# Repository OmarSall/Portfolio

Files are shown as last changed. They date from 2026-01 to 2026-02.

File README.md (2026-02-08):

# 🇪🇸 Portfolio de Ingeniería

Este repositorio contiene una selección de proyectos de ingeniería centrados en diseño mecánico, desarrollo estructural y optimización del rendimiento. El trabajo presentado incluye modelado CAD, procesos de diseño iterativo, validación mediante simulaciones (CFD / análisis estructural) y consideraciones de prototipado, principalmente en aplicaciones aeroespaciales y energéticas.

Los proyectos completos de ensamblaje y la documentación asociada están disponibles en este repositorio.

# 🇬🇧 Engineering Portfolio

This repository contains a selection of engineering projects focused on mechanical design, structural development and performance-driven optimization. The work presented includes CAD modeling, iterative design processes, simulation-based validation (CFD / structural analysis) and prototyping considerations, primarily within aerospace and energy-related applications.

The complete assembly projects and supporting documentation are available within this repository.

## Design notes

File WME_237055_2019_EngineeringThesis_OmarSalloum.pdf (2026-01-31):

Wydział Mechaniczno-Energetyczny kierunek studiów: Mechanika i Budowa Maszyn specjalność: Inżynieria lotnicza

# PRACA DYPLOMOWA INŻYNIERSKA

## Projekt wstępny wentylatora silnika dwuprzepływowego o ciągu

210 kN.

### Omar Salloum

Opiekun pracy
Dr inż. Roman Róziecki

Wrocław 2019

STRONA 3 Z 75

STRESZCZENIE

Celem pracy jest wykonanie projektu wstępnego jednostopniowego, naddźwiękowego wentylatora osiowego dla dwuprzepływowego turbinowego silnika odrzutowego o wysokim stopniu dwuprzepływowości charakteryzującego się siłą ciągu 210 kN. Poprzez analizę
układów | konstrukcyjnych | dwuprzepływowych | silników | odrzutowych | obecnie
eksploatowanych w statkach powietrznych linii lotniczych, uzyskano dane pozwalające wykonać wstępne obliczenia gazodynamiczne wentylatorowego silnika dwuprzepływowego. Następnie dokonano szczegółowych obliczeń gazodynamicznych jednostopniowego naddźwiękowego wentylatora. Na podstawie uzyskanych wyników sporządzono obliczenia wytrzymałościowe łopatek wirnikowych, zamków i tarczy wentylatora. Znając wymiary geometryczne wentylatora zaprojektowano w programie SolidWorks aparat kierujący, wirnik oraz pośrednie części konstrukcyjne tworzące razem jedną całość – wentylator. Bazując na wykonanym modelu sporządzono rysunki wykonawcze łopatki wirnikowej i tarczy wentylatora.

Słowa kluczowe: wentylator, silnik dwuprzepływowy.

ABSTRACT

The aim of this paper is to realize the preliminary draft of the one stage, supersonic, axial fan for the high by-pass ratio turbo-jet engine with the thrust of 210 kN. By the analysis of the high by-pass ratio turbo-jet engine that are currently applied for airline airplanes, obtained general and circumstantial gas-dynamic calculations. Taking into consideration gas-dynamic calculations, rotor blade, locks and fan’s disc strength calculations were made. Having known the geometry of the fan, digital 3D model of rotor, stator and intake casing were designed thanks to the computer aided design program SolidWorks. The last part of the paper is working drawing of the rotor blade and fan’s disc.

Keywords: fan, high by-pass ratio.

STRONA 4 z 75

STRONA 5 z 75

SPIS TREŚCI

5. Obliczenia wytrzymałościowe łopat wirnikowych, zamków i tarczy wentylatora na

5.1.Obliczenia wytrzymałościowe łopat wirnika wentylatora na rozciąganie siłą masową. 55

5.2.Obliczenia wytrzymałościowe zamków wentylatora na rozciąganie siłą masową. ...... 60

STRONA 6 z 75

WYKAZ SKRÓTÓW I OZNACZEŃ

A − pole powierzchni przekroju
a – lokalna prędkość dźwięku
C – godzinowe zużycie paliwa

Cs − sekundowe zużycie paliwa

c − prędkość bezwzględna

cP − ciepło właściwe przemiany izobarycznej

lw − praca efektywna wentylatora

m̅ − stosunek natężeń przepływów (współczynnik dwuprzepływowości silnika)

pH − ciśnienie statyczne otoczenia
R – indywidualna stała gazowa (dla powietrza R=287 J
kg∗K

)
u − prędkość obwodowa
w − prędkość względna

ηst

∗ − sprawność stopnia (wentylatora)

ηII − sprawność kanału zewnętrznego

κ − wykładnik izentropy (dla powietrza κ = 1,4)

μ − stopień obciążenia turbiny
π

∗ − spręż silnika

πS

∗ − spręż sprężarki

πW

∗ − spręż wentylatora

πWL

∗ − spręż wlotu

σWL – współczynnik strat ciśnienia całkowitego we wlocie

τ − względne zużycie paliwa

AK – aparat kierujący/wieniec kierujący/wieniec dyfuzorowy WW − wieniec wirnikowy
1 − 1 przekrój przed wieńcem wirnikowym wentylatora 1′ − 1′ przekrój za wieńcem wirnikowym wentylatora 1′′ − 1′′ przekrój za aparatem kierującym wentylatora

STRONA 7 z 75

WSTĘP

Wraz z rozwojem techniki i wymaganiami ekologicznymi dotyczącymi mniejszej emisji spalin silników lotniczych, zaczęły przeważać silniki dwuprzepływowe. Zadaniem wentylatora jest doprowadzenie powietrza o określonym strumieniu masy i ciśnieniu do wlotu sprężarki oraz tłoczenie wymaganej ilości powietrza do kanału zewnętrznego silnika pod ciśnieniem umożliwiającym wypływ z tego kanału z odpowiednią prędkością, przy zachowaniu właściwej wartości ciśnienia, umożliwiających wytworzenie ciągu. Obecnie dąży się do uzyskania coraz większej wartości strumienia masy powietrza w kanale zewnętrznym (większy stopień dwuprzepływowości), co implikuje mniejszą emisję spalin, mniejszy hałas, ale również większe wymiary promieniowe wentylatora (silnika). Skutkiem tego może być osiąganie prędkości naddźwiękowych końcówek łopat wentylatora co jest sporym problemem związanym z niestateczną pracą sprężarki wywołaną gwałtownymi zmianami ciśnienia, które zostały wygenerowane przez falę uderzeniową. Elementy wentylatorów są zagrożone podczas lotu na zderzenia z kroplami wody, bryłkami gradu, pojedynczymi ptakami lub ich stadami, a podczas startu czy lądowania na zderzenia z ziarnami piasku, wyrwanymi z podłoża i zassanymi przez wir wlotowy okruchami nawierzchni i innymi ciałami obcymi. Skutki zderzeń są bardzo groźne, ponieważ prędkości obwodowe wierzchołków łopat wentylatorów przekraczają 500 m/s, co stanowi o energii zderzeń zbliżonych do energii pocisków opuszczających lufy broni strzeleckiej. [1]

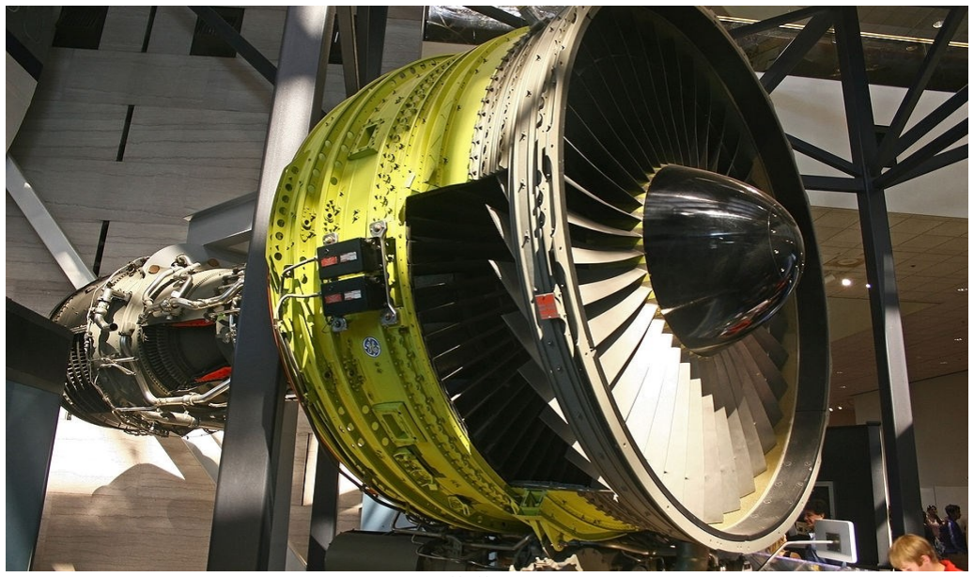
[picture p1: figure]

STRONA 8 z 75

1. ANALIZA | UKŁADÓW | KONSTRUKCYJNYCH | DWUPRZEPŁYWOWYCH
SILNIKÓW ODRZUTOWYCH.

Analiza układów konstrukcyjnych zawiera przegląd czterech najbardziej popularnych wentylatorowych silników turbinowo – odrzutowych o wysokim stopniu dwuprzepływowości stosowanych w lotnictwie cywilnym, w liniach lotniczych. Są to takie silniki jak: GE CF6, RB211, GE90 oraz GEnx. Znając rząd wartości charakterystycznych wielkości tj.: jednostkowe zużycie paliwa, sumaryczny strumień masy, stosunek natężeń przepływów, spręż oraz wymiary promieniowe wentylatora, dobrano wartości tych wielkości.

Pierwszym rozpatrywanym silnikiem jest turbowentylatorowy dwuprzepływowy, dwuwałowy silnik lotniczy CF6 firmy General Electric (USA) o ciągu 27 000 daN (rys.1.1). Charakteryzuje się jednostkowym zużyciem paliwa cj = 0,36 kg
| | daN∙ℎ

, sumarycznym strumieniem masy ṁ Σ = 874 kg
s

, stosunkiem natężeń przepływów m̅ = 5,3 oraz sprężem π

| | | ∗ = 34,8. Wymiary

promieniowe silnika GE CF6 o masie 5 091,6 kg są zdefiniowane przez jego średnicę o wartości d = 2 873,5 mm.
W większości przypadków średnica silnika jest ekwiwalentem średnicy zewnętrznej wentylatora.[2]

Rys. 1.1 Silnik GE CF6 [5].

GE CF6 napędza takie statki powietrzne jak: Airbus A330-200, A330 oraz Boeing 767,747. Jednostopniowy wentylator (WW+ AK) składa się z wieńca wirnikowego posiadającego 38 łopatek.

Łopatki wirnikowe wentylatora silnika GE CF6 posiadają półki, których obecność stanowi element antywibracyjny. Pod względem wytrzymałości piór łopatek wirnikowych półki stanowią poważne obciążenie – ze skokową zmianą naprężeń w miejscu usytuowania półki.[1]

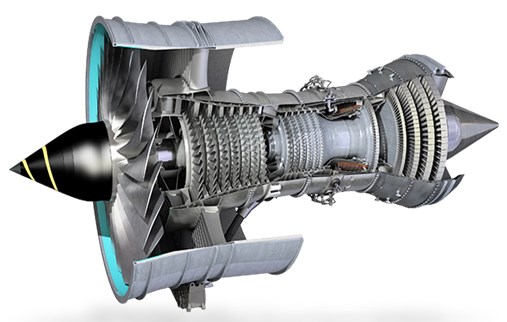
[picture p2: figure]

STRONA 9 z 75

Następnym | rozpatrywanym | silnikiem | jest | turbowentylatorowy, | dwuprzepływowy,
trójwałowegy silnik RB211 firmy Rolls – Royce (Wielka Brytania) przedstawiony w formie przekroju na rys.1.2. Silnik generuje siłę ciągu 33 430 daN oraz waży 6 271 kg. Charakteryzuje się sprężem o wartości π

∗ = 35,3; sumarycznym strumieniem masy ṁ Σ = 1 225 kg
| | | | | s ,
stosunkiem natężeń przepływów m̅ = 8,7 oraz jednostkowym zużyciem paliwa o wartości cj = 0,41 kg
daN∙ℎ

. Średnica silnika równoważna średnicy zewnętrznej wentylatora wynosi d = 3 944 mm.

Rys. 1.2 Przekrój silnika RB211. [7]

RB 211 napędza takie statki powietrzne jak: Boeing 747,757,767, Airbus A-380 oraz Tupolew Tu 204. [2]

W silniku RB 211 naddźwiękowy wentylator jest jednostopniowy (WW + AK), składa się z 22 tytanowych łopat o charakterystycznej szerokiej cięciwie aerodynamicznej oraz jest napędzany przez trójstopniową turbinę niskiego ciśnienia. [8]

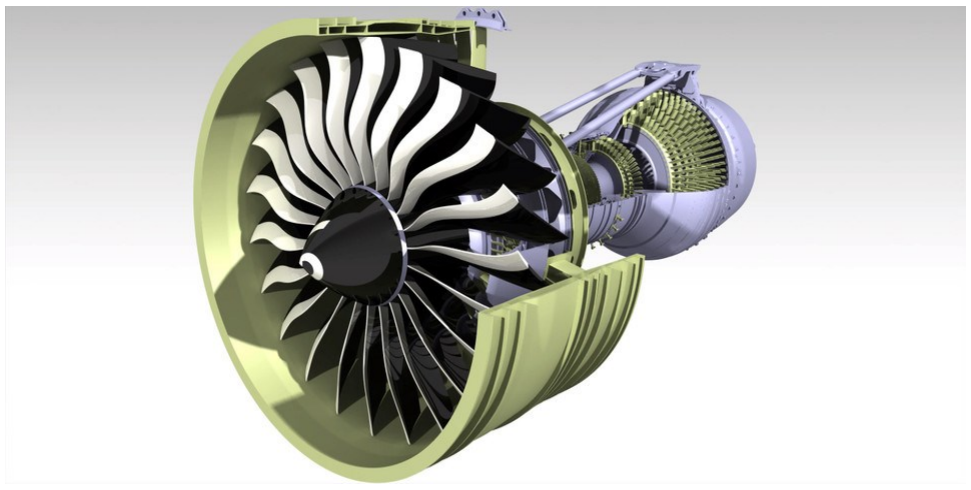
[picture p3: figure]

STRONA 10 z 75

Kolejnym | rozpatrywanym | silnikiem | w | analizie | układów | konstrukcyjnych | jest
turbowentylatorowy, dwuprzepływowy o dużym stopniu dwuprzepływowości silnik GE90 firmy General Electric (USA), przedstawiony w postaci przekroju na rys.1.3. GE90 charakteryzuje się sprężem π

∗ = 40, stosunkiem natężeń przepływów m̅ = 9, sumarycznym strumieniem masy ṁ Σ = 1 361 kg
| | | | s

, jednostkowym zużyciem paliwa cj = 0,29 kg
| daN∙ℎ
, | średnicą opisującą wymiary promieniowe d = 3 944 mm, siłą ciągu o
wartości 33 550 daN i masą 7 559 kg.

Rys. 1.3 Silnik GE90. [9]

GE90 napędza takie statki powietrzne jak Boeing 777-200/200ER. Naddźwiękowy wentylator składa się z wieńca wirnikowego, który posiada 22 łopaty o szerokiej cięciwie aerodynamicznej, wykonane z włókna węglowego, ze wzmacniającą matrycą epoksydową, oraz aparatu kierującego. Łopaty WW są unikalnie zaprofilowane, usprawniając aerodynamikę, co ma znaczący wpływ na jednostkowe zużycie paliwa. Krawędź natarcia
każdej | łopaty jest | wzmocniona | tytanową | nakładką. | Wentylator | jest | zasilany
6-stopniową turbiną niskiego ciśnienia. [10]

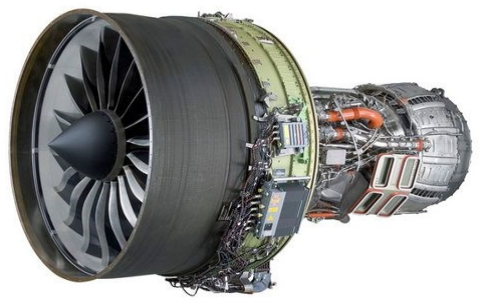
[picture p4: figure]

STRONA 11 z 75

Ostatnim analizowanym silnikiem jest turbowentylatorowy, dwuprzepływowy, dwuwałowy silnik GEnx (rys.1.4) firmy General Electric (USA) o sile ciągu 29 580 daN, charakteryzuje się sprężem π

∗ = 44,7; stosunkiem natężeń przepływów m̅ = 8, wagą 5 623 kg oraz średnicą d = 2 659,4 mm.

Rys. 1.4 Silnik GEnx [11]

GEnx napędza takie statki powietrzne jak Boeing 787, 747-8. Naddźwiękowy, jednostopniowy (WW+AK) wentylator zasilany jest 7-stopniową turbiną niskiego ciśnienia. Łopaty wieńca wirnikowego, charakteryzujące się szeroką cięciwą aerodynamiczną, wykonane są z materiału kompozytowego, m.in. włókna węglowego. Krawędź natarcia łopaty jest wzmocniona tytanową nakładką. W silniku GEnx zredukowano ilość łopat z 22 do 18. Opisana struktura wentylatora usprawnia aerodynamikę, zmniejsza zużycie paliwa, redukuje poziom hałasu oraz zwiększa siłę ciągu. [11],[12]

STRONA 12 z 75

Bazując na przedstawionej analizie konstrukcyjnej sporządzono tabelę zbiorczą (Tab.1.1), w celu oszacowania wartości niezbędnych do obliczeń gazodynamicznych silnika.

Tab. 1.1. Dane techniczne silników opisanych w rozdziale 1.

Dla | rozpatrywanych | parametrów | silników | GECF6, | RB211, | GE90 | oraz | GEnx
policzono wartości średnie.

Skorzystano ze wzoru na średnią arytmetyczną:

xśr =

xi

i=n
i=1
n

(1.1)

Wielkości charakteryzujące dany silnik zamieszczone w tabeli 1.1 mają indeksy: dla GE CF6 – 1, dla RB211 – 2, dla GE90 – 3 oraz dla GEnx – 4.

Zatem średnie jednostkowe zużycie paliwa wynosi:

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
+ cj
2

+ cj
3
3

(1.2)

Dla cj1

= 0,36 kg
daN∗ℎ

, cj2

= 0,41 kg
daN∗ℎ

, cj3

= 0,29 kg
daN∗ℎ

cj
śr

= 0,35

kg
daN ∙ ℎ
Średni sumaryczny strumień masy wynosi:

ṁ śr

=

ṁ
i

i=3
i=1
3

=

ṁ 1 + ṁ 2 + ṁ 3
3

(1.3)

Dla ṁ1 = 874 kg
s

, ṁ 2 = 1 225 kg
s

, ṁ 3 = 1 361 kg
s

ṁ śr = 1 153

kg
s
Silnik | Ciąg | Jednostkowe zużycie paliwa | Sumaryczny strumień masy | Stosunek natężeń przepływów | Spręż | Wymiary | Masa
| K | cj | ṁ Σ | m̅ | ∗ π | średnica
| daN | kg/daN·h | kg/s | - | - | mm | kg
GE CF6 | 27 000 | 0,36 | 874,0 | 5,3 | 34,8 | 2 873,5 | 5 091,6
RB211 | 33 430 | 0,41 | 1 225,0 | 8,7 | 35,3 | 3 944,0 | 6 271,0
GE90 | 33 550 | 0,29 | 1 361,0 | 9,0 | 40,0 | 3 944,0 | 7 559,0
GENX | 29 580 | - | - | 8,0 | 44,7 | 2 659,4 | 5 623,0

STRONA 13 z 75

Średni stosunek natężeń przepływów wynosi:

m̅śr =

m̅i

i=4
i=1
4

=

m̅1 + m̅2 + m̅3 + m̅4
4

(1.4)

Dla m̅1 = 5,3; m̅2 = 8,7; , m̅3 = 9; m̅4 = 8

m̅śr = 7,75

Średni spręż silnika wynosi:

πśr

∗
=

πc i

i=4
i=1
4

=

πc1 + πc 2 + πc3 + πc4
4

(1.5)

Dla π

∗
1 = 34,8; π

∗
2 = 35,3; π

∗
3 = 40; π

∗
4 = 44,7

π

∗
śr = 38,7

Średnia średnica silnika wynosi:

dśr =

dśr

i=4
i=1
4

=

d1 + d2 + d3 + d4
4

(1.6)

Dla d1 = 2 873,5 mm, d2 = 3 944 mm, d3 = 3 944 mm, d4 = 2 659,4 mm

dśr = 3 355,2 mm
Średnia masa silnika wynosi:

mśr =

mi

i=4
i=1
4

=

m1 + m2 + m3 + m4
4

(1.7)

Dla m1 = 5 091 kg, m2 = 6 271 kg, m3 = 7 559 kg, m4 = 5 623 kg

mśr = 6 136 kg

Na podstawie powyższych układów konstrukcyjnych dwuprzepływowych silników odrzutowych, w celu przeprowadzenia obliczeń gazodynamicznych silnika dobrano:

- Wartość stosunku natężeń przepływów m̅ = 7,75
- Założono spręż silnika πzał

∗ = 30

Średnie wartości jednostkowego zużycia paliwa, średnicy silnika, sumarycznego strumienia masy oraz masy silnika będą potrzebne w dalszej części pracy, w celu porównania z wartościami wyliczonymi. Dzięki takiemu porównaniu można dowiedzieć się czy uzyskane wartości są zbliżone do wartości powyższych wielkości charakteryzujących obecnie eksploatowane silniki w przemyśle lotniczym.

STRONA 14 z 75

### 2. WSTĘPNE OBLICZENIA GAZODYNAMICZNE SILNIKA

W celu przeprowadzenia wstępnych obliczeń gazodynamicznych wentylatorowego silnika dwuprzepływowego założono pracę silnika w warunkach statycznych na ziemi (cH = 0, MaH = 0, TH

∗ = 288,15 K, pH = 101325 Pa) oraz temperaturę całkowitą przed turbiną T3

∗ = 1550 K.

Na podstawie analizy przeprowadzonej w rozdziale 1 dobrano wartość stosunku natężeń przepływów m̅ = 7,75.

Założono spręż silnika πzał

∗ = 30.

Miernikiem efektywności działania wlotu jest jego spręż:

πWL

∗
=

p1

∗
pH

(2.1)

p1

∗
- ciśnienie całkowite przed wieńcem wirnikowym wentylatora

Straty ciśnienia we wlocie określa współczynnik strat ciśnienia całkowitego:

σWL =

p1

∗
pH

∗

(2.2)

Parametry spiętrzenia można wyrazić jako funkcje gazodynamiczne liczby Macha i statycznej wartości danego parametru:

2 2 2 c c c κ − 1 T ∗ = T + = T 1 + = T 1 + = T 1 + Ma 2 κ 2 2cp 2 2 RT a 2 κ − 1 κ − 1

| (2.3)

T

∗ = T 1 +

κ − 1
2

Ma

2

Proces spiętrzenia strumienia (wyhamowywania) potraktowano jako izentropowy:

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
∗ = p 1 +

κ − 1
2

Ma

2

κ
κ−1
(2.4)

Przekształcając wzór (2.1):

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
(2.5)

oraz wykorzystując zależność (2.4) otrzymano:

πWL

∗
= σWL 1 +

κ − 1
2

Ma

2

κ
κ−1
(2.6)

STRONA 15 z 75

Zatem zakładając warunki statyczne na ziemi (podstawiając do wzoru 2.6 Ma = 0 oraz σWL = 0,99 (krótki wlot powietrza)) spręż wlotu wynosi:

πWL

∗
= σWL = 0,99 ≈ 1

### 2.1. PRACA OBIEGU

Rozporządzalną (użyteczną) pracę obiegu w kanale wewnętrznym określa następujący wzór:

lob =

κ
κ − 1

RTH

eI − 1

ηprs
I

kIΔI

∗ηprs
I

ηprr
I
eI
− 1 | (2.7)

W celu wyznaczenia wartości pracy obiegu należy wyznaczyć:

a) Stopień podgrzania powietrza sprężanego izentropowo w silniku

epoc zI

= πzał

∗

κ−1
κ | (2.8)

epoczI = 30

1,4−1
1,4 = 2,642
b) Sprawność procesu sprężania w silniku

ηprs
I

= 0,83… 0,85; założono ηprs
I

= 0,84

c) Stopień podgrzania powietrza w silniku

ΔI

∗ =

1550
288,15

= 5,379

d) Sprawność procesu rozprężania spalin w silniku

ηprr
I

= 0,88 … 0,92; założono ηprr
I

= 0,9

e) Współczynnik k uwzględniający różnicę między ciepłami właściwymi spalin i powietrza

Wartość współczynnika kI odczytano z wykresu (rys.2.1.) Temperatura całkowita przed turbiną wynosi T3

∗ = 1550 K, zatem dla sprężu silnika πzał

∗ = 30, dobierając krzywą
pomiędzy krzywymi dla wartości T3

∗ = 1400 K i T3

∗ = 1600 K można aproksymować wykres funkcji, która przyjmuję wartość 1,045.

ΔI

∗
=

T3

∗

TH

(2.9)

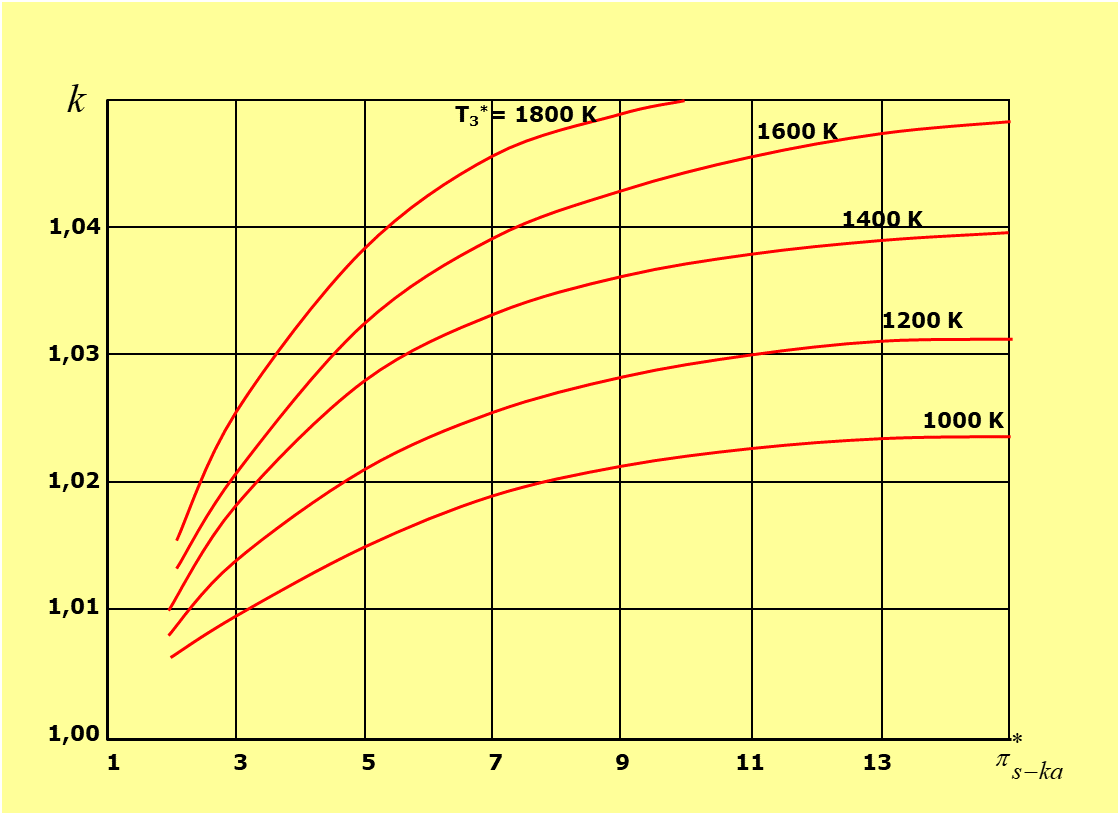
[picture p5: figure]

STRONA 16 z 75

Rys. 2.1. Zależność współczynnika k od sprężu silnika i temperatury przed turbiną. Zatem:
kI = 1,045
Podstawiając powyższe wartości do wzoru (2.7) otrzymano wartość lob = 344,283 kJ
kg

W celu optymalizacji pracy obiegu należy ją rozpatrzeć jako funkcję od zmiennej e [lob = f(e)]. Różniczkując badaną funkcję po zmiennej e oraz przyrównując wyliczoną pochodną funkcji do zera, można otrzymać optymalną wartość stopnia podgrzania powietrza sprężanego izentropowo w silniku (eopt), dającą maksymalną wartość pracy obiegu (ekstremum funkcji lob = f(e)).

lob max

= f(eopt
I
) | (2.10)

∂lob
∂eI

=

∂
∂eI

κ
κ − 1

RTH

eI − 1

ηpr sI

kIΔI

∗ηpr sI
ηpr rI
eI
− 1 | (2.11)

∂lob
∂eI

=

κ
κ − 1

RTH

kIΔI

∗ηpr rI
eI

2 −

1

ηpr sI

(2.12)

∂lob
∂eI

= 0 ⇒

kIΔI

∗ηpr rI
eI

2 =

1

ηpr sI

→ eoptI

= kIΔI

∗ηpr sI
ηpr rI
(2.13)

Podstawiając eoptI = 2,061 do wzoru na rozporządzalną pracę obiegu otrzymano:

lob max

| = f eop tI

= 388,239

kJ
kg

STRONA 17 z 75

Na podstawie optymalnej wartości stopnia podgrzania powietrza sprężanego izentropowo w silniku, która daje maksymalną wartość pracy obiegu, można wyliczyć optymalną wartość sprężu silnika:

eop tI

= κΔI

∗ηpr sI
ηpr rI

= πoptI

∗

κ−1
κ ⟹ πoptI

∗
= (kIΔI

∗ηpr sI
ηpr rI

)

κ
2(κ−1)
(2.14)

Zatem, dla: kI = 1,045; ηprrI = 0,9; ΔI

∗ = 5,379; ηprsI = 0,84; otrzymano:

πoptI

∗
= (1,045 ∙ 5,379 ∙ 0,84 ∙ 0,9)

1,4
2(1,4−1) = 12,577

Optymalna wartość stopnia podziału pracy obiegu między kanały silnika, odpowiadająca maksymalnemu ciągowi jednostkowemu i minimalnemu zużyciu paliwa można wyrazić zależnością:

βopt =

ηII −

cH

2

2lob

(1 − ηII

)
1
m̅

− ηII

(2.15)

Dla cH = 0:

βopt =

ηII
1
m̅

− ηII

(2.16)

Zakładając wartość sprawności kanału zewnętrznego ηII = 0,77 i m̅ = 7,75:

βopt =

0,77
1
7,75 − 0,77

= 0,85

Dla każdej wartości stopnia podziału pracy obiegu między kanały silnika przyporządkowana jest określona wartość sprężu wentylatora (wzrost β odpowiada wzrostowi sprężu wentylatora).

πW

∗
opt

=

βopt

lob ηW

∗

m̅

κ
κ − 1

RTH

+ 1

κ
κ−1
(2.17)

Zakładając wartość sprawności wentylatora ηW

∗ = 0,88; lob = lobmax = 388,239 kJ kg

;
TH = 288,15 K:

πWopt

∗ =

0,85 ∙ 388,239 ∙ 0,88

7,75 ∙

1,4
1,4 − 1

287 ∙ 288,15

+ 1

1,4
1,4−1
= 1,5

STRONA 18 z 75

Ciąg jednostkowy można wyliczyć ze wzoru:

kj =

1
1 + m̅

kj
I

+ m̅kJ
II

(2.18)

Ciąg jednostkowy kanału wewnętrznego:

Dla cH = 0 oraz lob = lobmax

kjI

= 2(1 − β)lob
(2.20)

kj
I

= 2(1 − 0,85) ∙ 388 239 = 333,83

m
s

Ciąg jednostkowy kanału zewnętrznego:

kj
II

= 2

β
m̅

lob +

cH

2
2

ηII − cH

(2.21)

Dla warunków statycznych oraz lob = lobmax :

kj
II

= 2

β
m̅

lob ηII

(2.22)

kj
II

= 2 ∙

0,85
7,75 ∙ 388 239 ∙ 0,77 = 257,05

m
s

Zatem wartość ciągu jednostkowego wynosi:

kj =

1
1 + 7,75

(333,83 + 7,75 ∙ 0,77) = 265,82

m
s

Strumień masy powietrza w zależności od wymaganego ciągu można wyznaczyć z poniższej zależności:

ṁ Σ =

K
kj

(2.23)

ṁ Σ =

210 000
265,82

= 790

kg
s

Korzystając z zależności określających stopień dwuprzepływowości i sumaryczny wydatek masowy powietrza można wyprowadzić wzór na strumień masy w kanale wewnętrznym i zewnętrznym.

kjI

= 2(1 − β)lob + cH

2 − cH
(2.19)

STRONA 19 z 75

m̅ =

ṁII
ṁ
I
ṁ Σ = ṁI + ṁII

⟹

ṁI =

ṁ Σ
m̅ + 1

ṁII =

ṁ Σm̅
m̅ + 1

(2.24)

ṁ

I =

790
7,75 + 1

= 89,26

kg
s

oraz ṁ

II =

790 ∙ 7,75
7,75 + 1

= 699,71

kg
s

Związek między podgrzaniem powietrza w sprężarce, a sprężem sprężarki przy założeniu
πWL

∗ ≈ 1:

πS

∗ =

eI

∗

κ
κ−1

πWL

∗ πW

∗ =

eI

∗

κ
κ−1
πW

∗

(2.25)

Postać analityczna funkcji opisującej zależność względnego zużycia paliwa od temperatury całkowitej za sprężarką dla poszczególnych wartości temperatury całkowitej przed turbiną:

τ = (3,1034 ∙ T3

∗ − 2,6897 ∙ T2
∗ − 380) ∙ 10⁻⁵
(2.26)

Temperaturę całkowitą za sprężarką, potrzebną do odczytu wartości τ można policzyć z następującego wzoru:

T2

∗ = TH

∗ 1 +

πS

∗

κ−1
κ − 1
ηS
∗ | (2.27)

Założono wartość sprawności efektywnej sprężarki w parametrach spiętrzenia: ηS

∗ = 0,85.

Jednostkowe zużycie paliwa definiuje wzór:

cj =

C
K

=

3600CS
K

=

3600 τ ṁ
I
K

(2.28)

Podstawiając zależności opisane wzorami (2.18), (2.20) oraz (2.22) do wzoru (2.23) otrzymano następującą zależność:

cj =

3600 ṁI

3,1034T3

∗ − 2,6897TH

∗
1 +

eI

∗

κ
κ−1
πWL

∗ πW

∗

κ−1
κ

ηS

∗

− 1

K

(2.29)

STRONA 20 z 75

Podstawiając wartości:

T3

∗ = 1550 K, TH

∗ = 288,15 K, πWL

∗ | = πopt
∗ | = 1,5; ηS = 0,85; ṁI = 89,26

kg
s

otrzymano:

cj =

3600 ∙ 89,26
3,1034 ∙ 1550 − 2,6897 ∙ 288,15

1 +

2,061

1,4
1,4−1
1,5

1,4−1
1,4

0,85

− 1

210 000

= 0,21

kg
daN ∙ ℎ

W celu wyznaczenia charakterystyki jednostkowego zużycia paliwa w funkcji stopnia podgrzania powietrza sprężanego izentropowo w silniku, należy wyprowadzić zależność wydatku masowego w kanale wewnętrznym od rozporządzalnej pracy obiegu.

Do wyznaczenia opisanej powyżej zależności należy skorzystać z poniższego wzoru:

K = ṁ Σkj = (ṁ

I + ṁ
II

)

1
1 + m̅

kj
I

+ m kj
II

(2.30)

Podstawiając zależność (2.20) i (2.22) otrzymano:

K = ṁ
I

(1 + m̅)

1
1 + m̅

2(1 − β)lob + m 2

β
m̅
lob ηII | (2.31)

ṁI =

K

lob 2(1 − β) + m̅(m̅ + 1) 2

β
m̅

ηII

(2.32)

Maksymalnej wartości pracy obiegu lobmax = 388,239 kJ
kg

, odpowiada wartość jednostkowego zużycia paliwa cj = 0,21 kg
daN∙ℎ

. Zakładając warunki ekonomiczne, wartość pracy obiegu

wynosi lobek = 138 kJ
kg

dla cjmin = 0,15 kg
daN∙ℎ

(rys.2.2). Wybór warunków ekonomicznych nie

jest najlepszym rozwiązaniem, głównie ze względu na zbyt duży spadek wartości lob (spadek o 64,46%) przy 25% spadku cj

Na podstawie powyższych zależności dobrano lob(e = 2,4) = 372 kJ
kg

oraz cj = 0,176 kg
daN∙ℎ
Zmniejsza to zużycie paliwa w ciągu sekundy o 0,14 kg
s

, co w przypadku dwugodzinnego lotu (dla samolotu pasażerskiego) oszczędza 1008 kg paliwa (1230 litrów).

STRONA 21 z 75

Cena nafty lotniczej wynosi średnio 4,62 zł/litr, zatem dla dwugodzinnego lotu potencjalne linie lotnicze mogłyby zyskać około 6 tys. złotych. Zakładając średni nalot 80 godzin w miesiącu (960 godzin w ciągu roku), roczny zysk osiąga wartość 2,88 mln PLN.

Finalne parametry gazodynamiczne silnika:

K = 210 kN, cj = 0,176

kg
daN ∙ ℎ

, lob = 372

kJ
kg , m̅ = 7,75 ; Δ

∗ = 5,379; ηprr = 0,9; πWL

∗ = 1

ηprs = 0,84; π

∗ = 21,4; ηII = 0,77; βopt = 0,85; πW

∗ = 1,48; kj
I

= 326,77

m
s

;

kj
II

= 251,61

m
s

; kj = 260,2

m
s

; ṁ Σ = 807,07

kg
s

; ṁ

I = 92,23

kg
s

; ṁ

II = 714,84 | kg s

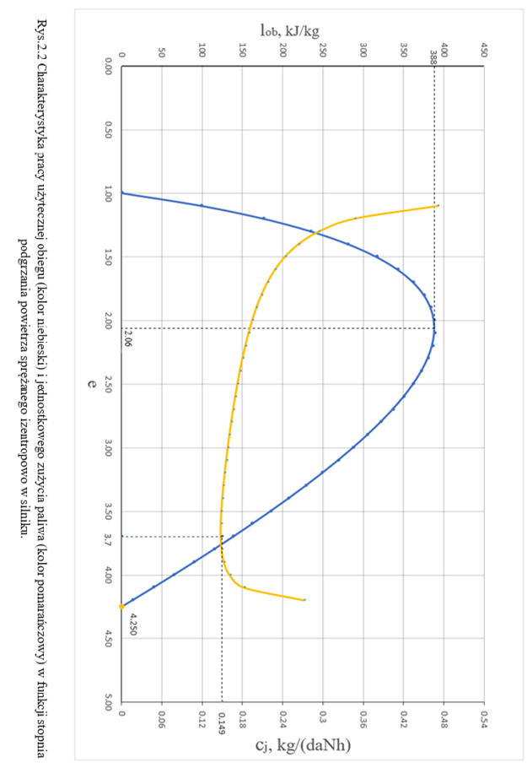
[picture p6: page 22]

STRONA 22 z 75

STRONA 23 z 75

### 3. WYMIARY GEOMETRYCZNE WENTYLATORA

W celu wyznaczenia wymiarów promieniowych wentylatora należy dobrać następujące wyjściowe parametry do obliczeń:

1. Prędkość bezwzględna strumienia powietrza c1 w przekroju wejściowym wieńca wirnikowego wentylatora (1-1): c1 = 170 m
s

,

2. Względna średnica wewnętrzna: D1

̅̅̅ =

Dw
Dz

= 0,28
3. Prędkość obwodowa wentylatora na średnicy zewnętrznej uz1 = 380 m
s

,
4. Liczba Macha w przekroju wejściowym na promieniu zewnętrznym odnosząca się do prędkości względnej: Mawl =

w1
a1

= 1,3

Na rysunku 3.1 przedstawiono charakterystyczne wielkości geometryczne opisujące wieniec wirnikowy (średnica zewnętrzna, średnica wewnętrzna i długość pióra łopaty), a na rysunku 3.2 zaznaczono trzy najważniejsze przekroje uwzględniane w obliczeniach (przekrój przed wieńcem wirnikowym 1 − 1, przekrój za wieńcem wirnikowym 1

′ − 1

′
, oraz za aparatem
kierującym 1′′ − 1′′).

Rys. 3.1. Podstawowe wielkości geometryczne opisujące wieniec wirnikowy.

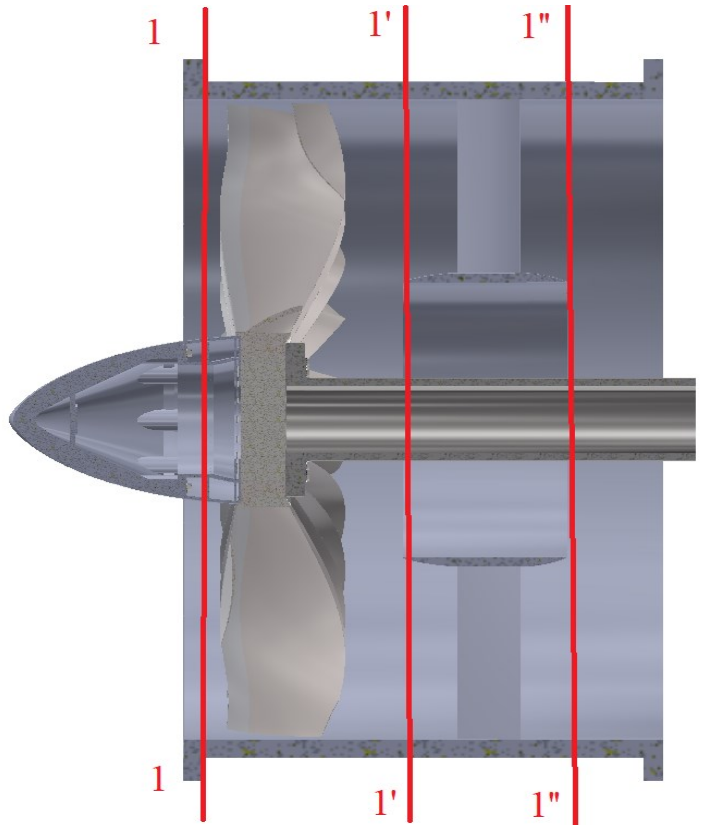
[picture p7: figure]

STRONA 24 z 75

Rys. 3.2 Charakterystyczne przekroje wentylatora (1 − 1, 1

′ − 1

′
, 1′′ − 1′′)

Parametry strumienia na średnim promieniu w przekroju przed wieńcem wirnikowym stopnia wentylatora:

- temperatura statyczna T1
(c1 = 170 m
s

; T1

∗ = TH

∗ = 288,15 K; R = 287 J
kg∙K

)

T1 = T1

∗ −

c1a

2

2

κ
κ − 1

R

(3.1)

T1 = 288,15 −

170²

2∙

1,4
1,4−1

∙287

= 273,77 K

- prędkość dźwięku a1:

a1 = κRT1
(3.2)

a1 = √1,4 ∙ 287 ∙ 273,77 = 331,66 m
s

STRONA 25 z 75

- prędkość względna w1:

w1 = Maw1

a1 | (3.3)

w1 = 1,3 ∙ 331,66 = 431,16 m
s
Prędkość obwodowa na średnim promieniu z uwzględnieniem profilowania łopatek wg prawa stałej reakcyjności (uz1 = 380 m
s

):

uśr1 = uz1

Dśr
Dz

= uz1

1 + D1

̅̅̅

2

2

(3.4)

Dla D1

̅̅̅ = 0,28 → u1śr = 380 ∙

1+0,28²

2

= 279 m
s

Pole powierzchni wieńca wirnikowego stopnia wentylatora:

Aw

=

ṁ Σ T1

∗
km ∙ j ∙ q1
- sinα1
- p1

∗

(3.5)

km − współczynnik korekcyjny uwzględniający prawo zmienności parametrów strumienia wzdłuż pióra łopatek oraz wpływ warstwy przyściennej kanału (km = 0,99)

j =

2
κ + 1

κ+1
2(κ−1)
∙

κ
R

(3.6)

Dla powietrza (κ = 1,4 oraz R = 287 J
kg∙K

):j ≈ 0,04041

Gęstość względna masy strumienia:

q1 =

cρ

ckr ρkr

=

Ma1√κRT

p
RT
2
κ − 1

κ+1
2(κ−1)

κ
R

p

∗
√T
∗

= Ma1

2
κ + 1

1 +

κ − 1
2

Ma1

2

−

κ+1
2(κ−1)
(3.7)

Dla przekroju 1-1 (dla Ma1 =

c1
a1

= 0,513):

q1 = 0,531 ∙

2
1,4 + 1

1 +

1,4 − 1
2

0,531²

−

1,4+1
2(1,4−1)
= 0,7596

Kąt zawarty między kierunkiem prędkości bezwzględnej w przekroju wejściowym, a płaszczyzną tego przekroju: α1 = 90°.

STRONA 26 z 75

Ciśnienie całkowite w przekroju 1-1 równe jest ciśnieniu całkowitemu w przekroju przed silnikiem (H-H) pomniejszonemu o straty ciśnienia całkowitego:

p1

∗
= σWL
- pH

∗
= σWLpH 1 +

κ − 1
2

MaH

2

κ
κ−1
(3.8)

W warunkach statycznych (MaH = 0) oraz dla σWL = 0,99:

p1

∗ = 101325 ∙ 0,99 = 100 312 Pa

Korzystając z równania ciągłości:

ṁ = A ∙ sinα ∙ c ∙ ρ | (3.9)

oraz gęstości względnej masy strumienia (3.7), otrzymano wzór (3.5).

Pole powierzchni wentylatora wynosi:
(sinα1 = 1; km = 0,99;j ≈ 0,04041; q1 = 0,7596; ṁ Σ = 807,07 kg
s

; T1

∗ = TH

| ∗ = 288,15 K)

A1 =

807,07 288,15
0,99 ∙ 0,04041 ∙ 0,7596 ∙ sin90° ∙ 100 312 = 4,5 m²

Średnica zewnętrzna przekroju wejściowego wentylatora (D1

̅̅̅ = 0,28):

Dz1 =

4A1
π(1 − D1

̅̅̅

2
)

(3.10)

Dz1 =

4∙4,5
3,1415∙(1−0,28²
)

= 2,494 m

Średnica wewnętrzna przekroju 1-1:

Dw1
= D1

̅̅̅ ∙ Dz1
(3.11)

Dw1 = 0,28 ∙ 2,494 = 0,698 m

Wysokość pióra łopatki:

l1 =

Dz1 − Dw1
2

(3.12)

l1 =

2,494−0,698
2

= 0,898 m

Sprawność efektywna wentylatora:

ηW

∗ = ηSt

∗ = 0,88

STRONA 27 z 75

Prędkość obrotowa wirnika wentylatora (uz1 = 380 m
s

,Dz1 = 2,493 m):

n =

60uz1
πDz1

(3.13)

n =

60∙380
3,1415∙2,493

= 2 912 obr
min

W stopniu wentylatora (bądź sprężarki) składowa osiowa prędkości bezwzględnej spada średnio o około 5÷15 m/s.

Założono spadek wartości składowej osiowej prędkości bezwzględnej Δca = 10 m
s

Prędkość bezwzględna za aparatem kierującym wynosi:

c1′′ = c1 − Δca
(3.14)

Dla c1 = 170 m
s

→ c1

′′ = 170 − 10 = 160 m
s

Temperatura całkowita na średnim promieniu w przekroju wyjściowym (za AK wentylatora):

T1
′′

∗ = T1
∗ 1 +

πW

∗

κ−1
κ − 1
ηW
∗ | (3.15)

Dla T1

∗ = TH

∗ = 288,15 K; πW

∗ = 1,48 oraz ηW

∗ = 0,88

T1
′′

∗ = 288,15 1 +

1,48

1,4−1
1,4 − 1
0,88 = 327 K

Praca efektywna wentylatora:

lw

=

κ
κ − 1

R(T1

′′ − T1

∗
) | (3.16)

Dla R = 287 J
kg∙K

; T1
′′

∗ = 327 K i T1
∗ = 288,15 K w celu uzyskania założonego sprężu

wentylatora należy doprowadzić do każdego kilograma powietrza przepływającego przez wentylator pracę efektywną

lw =

1,4
1,4 − 1
- 287 ∙ (327 − 288,15) = 39,02

kJ
kg.

Wiedząc, że sumaryczny masowy wydatek powietrza wynosi ṁ Σ = 807,07 kg
s

, można
wyznaczyć moc do napędu wentylatora:

Nw

= ṁ Σ

- lw | (3.17)

Nw = 807,07 ∙ 39,02 = 31,492 MW

STRONA 28 z 75

### 4. SZCZEGÓŁOWE OBLICZENIA STOPNIA WENTYLATORA

Szczegółowe obliczenia stopnia wentylatora polegają na określeniu prędkości na promieniu wewnętrznym, średnim i zewnętrznym, wyznaczeniu gęstości palisady i zaprofilowaniu łopatek (wg prawa o stałej reakcyjności).[3]

### 4.1. OKREŚLENIE TRÓJKĄTÓW PRĘDKOŚCI NA ŚREDNIM PROMIENIU

Promień względny dla średniego promienia:

r̅śr̅ =

rśr
rz

(4.1)

Korzystając z zależności wiążącej średnią średnicę ze średnicą zewnętrzną dla łopatek o stałej reakcyjności:

Dśr
Dz

=

1 + D1

̅̅̅

2

2

(4.2)

dla D1

̅̅̅ = 0,28

Dśr
Dz

=

1 + 0,28²
2

= 0,734 → Dśr = 0,734 ∙ 2,494 = 1,831 m

rśr =

Dśr
2

=

1,831
2

= 0,916 m

Wiedząc, że rz =

Dz1
2

= 1,247 m wyznaczono:

r̅śr =

0,916
1,247 = 0,734

Ważnym parametrem stopnia jest tzw. reakcyjność stopnia, wyrażana stosunkiem pracy sprężania izentropowego w wieńcu łopatek wirnika do pracy sprężania izentropowego w stopniu:

ρ =

liz w

liz St

(4.3)

gdzie:

lizw − praca sprężania izentropowego w wieńcu łopatek wirnika

lizSt − praca sprężania izentropowego w stopniu

Reakcyjność charakteryzuje podział pracy sprężania izentropowego w stopniu pomiędzy wieńcem wirnika, a wieńcem dyfuzora.[3]

STRONA 29 z 75

Rozpatrywany stopień wentylatora jest stopniem o stałej reakcyjności. W takim stopniu składowa obwodowa prędkości bezwzględnej c1u zwiększa się w miarę zwiększania promienia.

Stopień o stałej reakcyjności wymaga spełnienia oczywistego warunku:

ρ = idem | (4.4)

oraz drugiego warunku, korzystnie wpływającego na sprawność stopnia, jakim może być między innymi stałość pracy efektywnej doprowadzonej do strumienia wzdłuż piór łopatek:

lw

= u ∙ Δwu

= idem | (4.5)

Warunek (4.3) można scharakteryzować następującym wzorem:

ρ = 1 −

c1u
u

−

Δwu
2u
= idem | (4.6)

Oznacza to, że wraz ze wzrostem zawirowania strumienia(Δwu), reakcyjność stopnia maleje (przy stałej wartości pozostałych parametrów).[3]

Prędkość obwodowa na średnim promieniu (r̅śr̅ = 0,734; u1z = 380 m
s

):

u1śr

= u1z

- r̅śr̅ | (4.7)

u1śr = 0,734 ∙ 380 = 279 m
s
Zawirowanie strumienia na średnim promieniu (lw = 39,02 kJ
kg

):

Δwuśr

=

lw u1śr | (4.8)

Δwuśr =

39 020
279

= 139,86 m
s
Współczynnik zawirowania definiuje wzór:

μśr

=

Δwuśr

u1śr

(4.9)

μśr =

139,86
279

= 0,501

Dla osiowego kierunku prędkości bezwzględnej przed wieńcem łopatek wirnika (tj. przy c1u = 0) reakcyjność stopnia na średnim promieniu wyraża wzór:

ρ = ρśr

= 1 −

μśr
2

= 1 −

Δwuśr
2uśr
= idem | (4.10)

ρ = 1 −

0,501
2

= 0,749

Oznacza to, że 74,9 % pracy sprężania izentropowego w stopniu przypada na wieniec wirnika.

STRONA 30 z 75

Trójkąty prędkości przed wieńcem wirnikowym, za wieńcem wirnikowym oraz prędkość bezwzględna za aparatem kierującym na średnim promieniu zostały przedstawione na rysunku 4.1.

Rys. 4.1. Trójkąty prędkości dla poszczególnych przekrojów na średnim promieniu.

Zależność opisująca kąt zawarty pomiędzy wektorem prędkości bezwzględnej c1śr

,
a wektorem prędkości obwodowej uśr1

(brak wstępnego zawirowania → c1uśr = 0):

α1śr

= arctg

c1

c1uśr

(4.11)

α1śr = arctg(∞) = 90°

Zależność opisująca kąt zawarty pomiędzy wektorem prędkości względnej w1śr , a wektorem
prędkości obwodowej uśr1

(c1śr = 170 m
s

, u1śr = u1śr

′ = uśr = 279 m s ):

β1śr

= arctg

c1aśr

uśr − c1uśr

(4.12)

β1śr = arctg

170
279 = 31,35°

STRONA 31 z 75

Składowa obwodowa prędkości bezwzględnej za wieńcem wirnikowym c1
′uśr

:

Δwuśr = 139,86

m
s

c1u
′
śr

= c1u

+ Δwuśr
(4.13)

c1
′uśr

= 139,86 m
s
Składowa osiowa prędkości bezwzględnej za wieńcem wirnikowym:

c1
′aśr

= 165

m
s

Zależność opisująca kąt zawarty pomiędzy wektorem prędkości względnej w1
′
śr

, a wektorem
prędkości obwodowej uśr (c1
′aśr

= 165 m
s

;uśr = 279 m
s

):

β1śr

′ = arctg

c1aśr
′
uśr − c1u
′
śr

(4.14)

β1śr

′ = arctg

165
279−139,86 = 49,85°

Kąt zawarty pomiędzy wektorem prędkości bezwzględnej c1
′
śr

, a wektorem prędkości
obwodowej uśr

:

α1śr

′ = arctg

c1aśr
′
c1u
′
śr

(4.15)

α1śr

′ = arctg

165
139,86 = 49,71°

Kąt skręcenia strumienia w palisadzie:

Δβśr

= β1śr

′ − β1śr
(4.16)

Δβśr = 49,85° − 31,35° = 18,5°

Prędkość bezwzględna za wieńcem wirnikowym (c1
′uśr

= 128,35 m
s

; c1
′aśr

= 165 m
s

):

c1śr

′ = c 1aśr
′

2 + c 1uśr
′

2
(4.17)

c1śr

′ = 165² + 139,86² = 216,3

m
s
Średnia temperatura statyczna za wieńcem wirnikowym:

T1śr

′ = T1śr

+ ρΔTst śr
(4.18)

gdzie:
ΔTstśr
– zmiana temperatury statycznej w stopniu na średnim promieniu

# STRONA 32 z 75 ΔTst śr

= T1śr

′′ − T1śr | (4.19)

Temperatura statyczna przed wieńcem wirnikowym:

(T1śr

∗ = 288,15 K; c1śr = 170 m
s

; cp = 1004,5

J
kg∙K

)

T1śr

= T1

∗
śr −

c1śr

2
2cp

(4.20)

T1śr = 288,15 −

170²

2∙1004,5

= 273,76 K

Temperatura statyczna za aparatem kierującym:

(T1śr
′′

∗ = 327 K; c1śr

′′ = 160 m
s

; cp = 1004,5

J
kg∙K

)

T1
′′ śr

= T1
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
(4.21)

T1śr

′′ = 327 −

160²

2∙1004,5

= 314,26 K

Zatem:

ΔTstśr = 314,26 − 273,76 = 40,5 K

Dla ρ = 0,749

T1śr

′ = 273,76 + 0,749 ∙ 40,5 = 304 K

Prędkość dźwięku za wieńcem wirnikowym wentylatora:

a1śr

′ | = κRT1śr
′ | (4.22)

a1śr

′ = √1,4 ∙ 287 ∙ 304 = 349,49 m
s

Liczba Macha za wieńcem wirnikowym wentylatora (c1śr

′ = 216,3

m
s

):

Ma1śr

′ =

c1
′
śr
a1śr
′

(4.23)

Ma1w

′ =

216,3
348,49

= 0,618

c1śr = 170 m
s

; c1śr

′′ = 160 m
s

; c1
′asr

= 165 m
s

; uśr = 279 m
s

; c1
′uśr

= 139,86 m
s

;
α1śr = 90°; α1śr
′ | = 49,71° ; β1śr = 31,35°; β1śr
′ | = 49,85° ; c1śr
′ | = 216,3

m
s

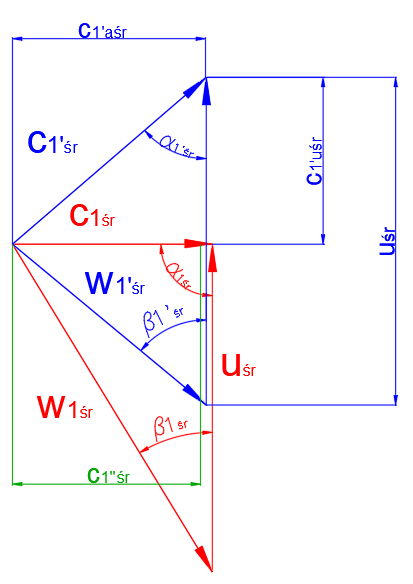
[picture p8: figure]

STRONA 33 z 75

Na rysunku 4.2 przedstawiono trójkąty prędkości w trzech rozpatrywanych przekrojach wentylatora (1 − 1, 1

′ − 1

′
, 1

′′ − 1

′′).

Rys. 4.2. Trójkąty prędkości przed wieńcem wirnikowym (kolor czerwony), za wieńcem wirnikowym (kolor niebieski) oraz za aparatem kierującym (kolor zielony) na średnim promieniu.

### 4.2. OKREŚLENIE TRÓJKĄTÓW PRĘDKOŚCI NA PROMIENIU WEWNĘTRZNYM

Promień względny dla promienia wewnętrznego:

r̅w̅ =

rw
rz

(4.24)

rw̅ =

0,349
1,247

= 0,279

Prędkość obwodowa na wewnętrznym promieniu (r̅w̅ = 0,279; u1z = 380 m
s

):

u1w

= u1z

- r̅w̅ | (4.25)

uw1 = 380 ∙ 0,279 = 106,02 m
s

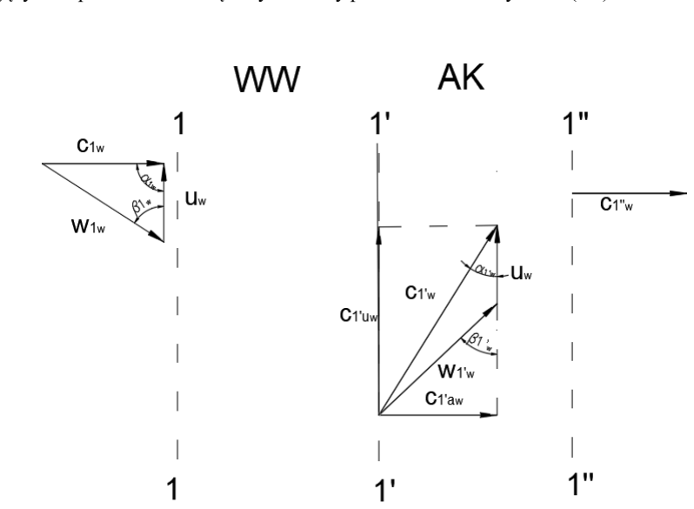
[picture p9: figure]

STRONA 34 z 75

Zawirowanie strumienia na promieniu wewnętrznym (lw = 39,02 kJ
kg

):

Δwuw
=

lw
uw1

(4.26)

Δwuw =

39 020
106,02

= 368,04 m
s

Współczynnik zawirowania definiuje wzór: (ρw = ρśr = ρz = ρ = 0,749)

μw

= 2 ∙ (1 − ρ ) | (4.27)

μw = 2 ∙ (1 − 0,749) = 0,502

Trójkąty prędkości przed wieńcem wirnikowym, za wieńcem wirnikowym oraz za aparatem kierującym na promieniu wewnętrznym zostały przedstawione na rysunku (4.3).

Rys. 4.3. Trójkąty prędkości dla poszczególnych przekrojów na wewnętrznym promieniu.

Zależność opisująca kąt zawarty pomiędzy wektorem prędkości bezwzględnej c1w

, a wektorem
prędkości obwodowej uw1

(brak wstępnego zawirowania → c1uw = 0):

α1w

= arctg

c1

c1u

(4.28)

α1w = arctg(∞) = 90°

STRONA 35 z 75

Zależność opisująca kąt zawarty pomiędzy wektorem prędkości względnej w1w , a wektorem
prędkości obwodowej uw1

(c1 = 170 m
s

, uw = 106,02 m
s

):

β1w

= arctg

c1
uw − c1u

(4.29)

β1w = arctg

170
106,02 = 58,05°

Składowa obwodowa prędkości bezwzględnej za wieńcem wirnikowym c1
′uw

:

Δwuw = 368,04

m
s

c1u
′
w

= c1u

+ Δwuw | (4.30)

c1
′uw

= 368,04 m
s
Składowa osiowa prędkości bezwzględnej za wieńcem wirnikowym:

c1
′aw

= 165

m
s

Zależność opisująca kąt zawarty pomiędzy wektorem prędkości względnej w1 ′w, a wektorem
prędkości obwodowej uw1
′

(c1
′aw

= 165 m
s

; uw1 = uw1

′ = uw = 106,02 m
s

):

β1w

′ = arctg

c1aw
′
uw − c1u
′
w

(4.31)

β1w

′ = arctg |
165

106,02−368,04| = 32,2°

Kąt zawarty pomiędzy wektorem prędkości bezwzględnej c1

′w , a wektorem prędkości
obwodowej uw1
′

:

α1w

′ = arctg

c1aw
′
c1u
′
w

(4.32)

α1w

′ = arctg

165
368,04 = 24,1°

Kąt skręcenia strumienia w palisadzie:

Δβw

= β1w

′ − β1w
(4.33)

Δβw = |32,2° − 58,05°| = 25,85°

Prędkość bezwzględna za wieńcem wirnikowym (c1uw

′ = 368,04 m
s

; c1
′aw

= 165 m
s

):

# STRONA 36 z 75 c1w

′ = c 1aw
′

2 + c 1uw
′

2
(4.34)

c1w

′ = 165² + 368,04² = 403,33 m
s
Średnia temperatura statyczna za wieńcem wirnikowym:

T1w

′ = T1 + ρΔTstw
(4.35)

gdzie:
ΔTstw
– zmiana temperatury statycznej w stopniu na promieniu wewnętrznym

ΔTst w

| = T1w ′′ − T1w
(4.36)

Temperatura statyczna przed wieńcem wirnikowym: (T1w

∗ = 288,15 K; c1w = 170 m
s

; cp = 1004,5

| J kg∙K )

T1w

= T1

∗
w −

c1w

2
2cp

(4.37)

T1w = 288,15 −

170²

2∙1004,5

= 273,76 K

Temperatura statyczna za aparatem kierującym: (T1w
′′

∗ = 327 K; c1w

′′ = 160 m
s

; cp = 1004,5

J
kg∙K

)

T1
′′
w

= T1
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
(4.38)

T1w

′′ = 327 −

160²

2∙1004,5

= 314,26 K

Zatem:

ΔTstw = 314,26 − 273,76 = 40,5 K

Dla ρ = 0,789

T1w

′ = 273,76 − 0,789 ∙ 40,5 = 295,33 K

Prędkość dźwięku za wieńcem wirnikowym wentylatora:

a1w

′ = κRT1śr ′
w

(4.39)

a1w

′ = 1,4 ∙ 287 ∙ 295,33 = 344,47 m
s

STRONA 37 z 75

Liczba Macha za wieńcem wirnikowym wentylatora (c1w

′ = 403,33 m
s

):

Ma1w

′ =

c1
′
w
a1w
′

(4.40)

Ma1w

′ =

403,33
344,47

= 1,17

c1w = 170 m
s

; c1w

′′ = 160 m
s

; c1
′aw

= 165 m
s

; uw = 106,02 m
s

; c1
′uw

= 368,04 m
s

;
α1w = 90°; α1w

′ = 24,1° ; β1w = 58,05°; β1w

′ = 32,2° ; c1w

′ = 403,33 m
s

Na rysunku 4.4 przedstawiono trójkąty prędkości w trzech rozpatrywanych przekrojach wentylatora (1 − 1, 1

′ − 1

′
, 1

′′ − 1

′′).

Rys. 4.4. Trójkąty prędkości przed wieńcem wirnikowym (kolor czerwony), za wieńcem wirnikowym (kolor niebieski) oraz za aparatem kierującym (kolor zielony) na wewnętrznym promieniu.

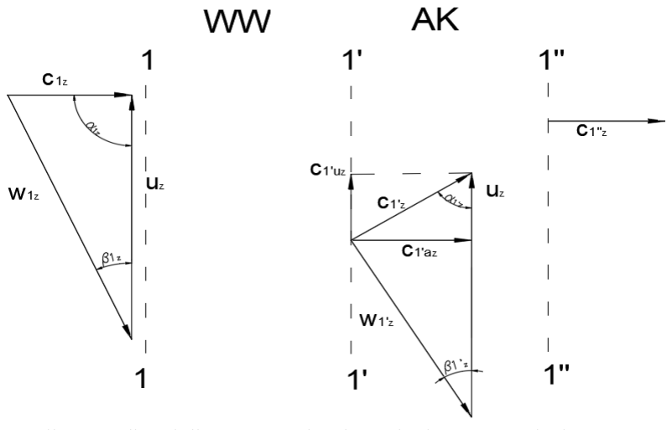
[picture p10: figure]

STRONA 38 z 75

### 4.3. OKREŚLENIE TRÓJKĄTÓW PRĘDKOŚCI NA PROMIENIU ZEWNĘTRZNYM

Promień względny dla promienia zewnętrznego:

r̅z =

rz
rz

(4.41)

r̅z = 1

Prędkość obwodowa na zewnętrznym promieniu:
uz1 = 380 m
s
Zawirowanie strumienia na promieniu zewnętrznym (lw = 39,02 kJ
kg

):

Δwuz

=

lw
uz1

(4.42)

Δwuz =

39 020
380

= 102,68 m
s
Współczynnik zawirowania definiuje wzór:

μz

=

Δwuz
uz1

(4.43)

μz =

102,68
380

= 0,2702

Trójkąty prędkości przed wieńcem wirnikowym, za wieńcem wirnikowym oraz za aparatem kierującym na promieniu zewnętrznym zostały przedstawione na rysunku (4.5).

Rys. 4.5. Trójkąty prędkości dla poszczególnych przekrojów na promieniu zewnętrznym.

STRONA 39 z 75

Zależność opisująca kąt zawarty pomiędzy wektorem prędkości bezwzględnej c1z

, a wektorem
prędkości obwodowej uz1

(brak wstępnego zawirowania → c1uz = 0):

α1z

= arctg

c1

c1u

(4.44)

α1z = arctg(∞) = 90°

Zależność opisująca kąt zawarty pomiędzy wektorem prędkości względnej w1z , a wektorem
prędkości obwodowej uz1

(c1z = 170 m
s

, uz = 380 m
s

):

β1z

= arctg

c1az
uz − c1uz

(4.45)

β1z = arctg

170
380 = 24,1°

Składowa obwodowa prędkości bezwzględnej za wieńcem wirnikowym c1
′uz

:

Δwuz = 102,68

m
s

c1u
′
z

= c1uz

+ Δwuz
(4.46)

c1
′uz

= 102,68 m
s
Składowa osiowa prędkości bezwzględnej za wieńcem wirnikowym:

c1
′az

= 165 m
s
Zależność opisująca kąt zawarty pomiędzy wektorem prędkości względnej w1
′z

, a wektorem
prędkości obwodowej uz (c1
′az

= 165 m
s

; u1z = u1z

′ = uz = 380 m
s

):

β1z

′ = arctg

c1az
′
uz − c1u
′
z

(4.47)

β1z

′ = arctg

165
380−102,68 = 30,75°

Kąt zawarty pomiędzy wektorem prędkości bezwzględnej c1
′z

, a wektorem prędkości
obwodowej uz

:

α1z

′ = arctg

c1az
′
c1u
′
z

(4.48)

α1z

′ = arctg

165
102,68 = 58,1°

STRONA 40 z 75

Kąt skręcenia strumienia w palisadzie:

Δβz

= β1z
′ − β1z
(4.49)

Δβz = 30,75° − 24,1° = 6,65°

Prędkość bezwzględna za wieńcem wirnikowym (c1
′uz

= 102,68 m
s

; c1
′az

= 165 m
s

):

c1z

′ = c
1az

′

2 + c 1uz
′

2
(4.50)

c1z

′ = 165² + 102,68² = 194,34 m
s
Średnia temperatura statyczna za wieńcem wirnikowym:

T1z

′ = T1z

+ ρΔTst z
(4.51)

gdzie:
ΔTstz
– zmiana temperatury statycznej w stopniu na promieniu zewnętrznym

ΔTst z

= T1z

′′ − T1z | (4.52)

Temperatura statyczna przed wieńcem wirnikowym: (T1z

∗ = 288,15 K; c1z = 170 m
s

; cp = 1004,5

J
kg∙K

)

T1z

= T1

∗
z −

c1z

2
2cp

(4.53)

T1z = 273,76 K

Temperatura statyczna za aparatem kierującym: (T1z
′′

∗ = 327 K; c1z

′′ = 160 m
s

; cp = 1004,5

J
kg∙K

)

T1
′′
z

= T1
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
(4.54)

T1z

′′ = 327 −

160²

2∙1004,5

= 314,26 K

Zatem:

ΔTstz = 40,5 K

Dla ρ = 0,789

T1z

′ = 295,33 K

STRONA 41 z 75

Prędkość dźwięku za wieńcem wirnikowym wentylatora:

a1z

′ = κRT1z
′ | (4.55)

a1z

′ = 344,47 m
s

Liczba Macha za wieńcem wirnikowym wentylatora (c1z

′ = 194,34 m
s

):

Ma1z

′ =

c1
′
z
a1z
′

(4.56)

Ma1w

′ =

194,34
344,47

= 0,564

c1z = 170 m
s

; c1z

′′ = 160 m
s

; c1
′az

= 165 m
s

; uz = 380 m
s

; c1
′uz

= 102,68 m
s

;
α1z = 90°; α1z

′ = 58,1° ; β1z = 24,1°; β1z

′ = 30,75° ; c1z

′ = 194,34 m
s
Na rysunku 4.6 przedstawiono trójkąty prędkości w trzech rozpatrywanych przekrojach wentylatora (1 − 1, 1

′ − 1

′
, 1

′′ − 1

′′).

Rys. 4.6. Trójkąty prędkości przed wieńcem wirnikowym (kolor czerwony), za wieńcem wirnikowym (kolor niebieski) oraz za aparatem kierującym (kolor zielony) na promieniu zewnętrznym.

STRONA 42 z 75

4.4. | WYKREŚLENIE | PROFILU | ŁOPATY | WIEŃCA | WIRNIKOWEGO | NA | PROMIENIU
ZZZZWEWNĘTRZNYM.

Opływanie palisad wentylatora strumieniem naddźwiękowym związane jest z powstawaniem fal uderzeniowych. Sprężanie strumienia nawet w prostopadłej fali uderzeniowej przy umiarkowanych liczbach Macha MaHw1 = 1,3 − 1,5 jest wysokosprawne, gdyż wtedy współczynnik strat spiętrzenia w fali wynosi σud = 0,9 − 0,95. Sprężanie w układzie fal uderzeniowych jest jeszcze sprawniejsze. W ten sposób, w zakresie wymienionych prędkości strumienia, obecności fali uderzeniowej przy odpowiednim doborze parametrów profilu nie przeszkadza w osiągnięciu odpowiednio wysokiej sprawności stopnia naddźwiękowego, sięgającego rzędu η ≈ 0,86 − 0,9. [3]

Profile łopaty wentylatora zostały wykreślone na trzech promieniach (wewnętrznym, średnim oraz zewnętrznym).

Dla wentylatora, w celu zwiększenia stateczności jego pracy przy zmianie kąta β1, wskazane jest zwiększenie wartości Δβ w granicach 15-20 %.
Zatem, nominalnym kątem skręcenia strumienia dla wentylatora będzie:
(Δβw = 25,85°)
Δβw
| | | ∗
= 1,18 ∙ Δβw
(4.57)

Δβw

∗ = 1,18 ∙ 25,85 = 30,5°

Na podstawie analizy układów konstrukcyjnych dwuprzepływowych silników turbinowo odrzutowych założono:

- Liczba łopat wieńca wentylatora: z = 22
- Cięciwa łopat wieńca wirnikowego wentylatora na wewnętrznym promieniu:
bw = 0,21 m

Założono kąt napływu palisad: i = −2°

Kąt wygięcia profilu na promieniu wewnętrznym:

Θw =

Δβw

∗ − i

1 − m ∙

tw
bw

(4.58)

gdzie:

m = 0,18 + 0,23 ∙

2a
bw

2
− 0,1 ∙

β1w
′
50°

(4.59)

dla β1w

′ = 32,2° oraz

a
bw

= 0,45 ⟶ m = 0,18 + 0,23 ∙ 0,9

2 − 0,1 ∙

32,2°
50°

= 0,3019

STRONA 43 z 75

Podziałka palisady łopat wirnika wentylatora na promieniu wewnętrznym: (Dw = 0,698 m; z = 22)

tw =

πDw
z

(4.60)

tw =

3,1415∙0,698
22

= 0,099

Zatem kąt wygięcia profilu wynosi (Δβw

∗ = 25,85°;i = −2°):

Θw =

30,5 + 2

1 − 0,3019 ∙

0,099
0,21

= 41°

Kąt odchylenia strumienia:

δ = m ∙ Θw ∙

tw
bw

(4.61)

δ = 0,3019 ∙ 41° ∙

0,099
0,21

= 8,49°

Przedni kąt wygięcia profilu:

χ1w = Θw ∙ 1,5 − 2 ∙

a
bw

(4.62)

χ1w = 41° ∙ (1,5 − 2 ∙ 0,45) = 24,6°

Tylny kąt wygięcia profilu:

χ1
′
w

= Θw − χ1w
(4.63)

χ1w

′ = 41° − 24,6° = 16,4°

Kąt konstrukcyjny na wejściu z palisady (β1w = 58,05°; i = −2°):

β1kw
= β1w
+ i | (4.64)

β1kw

= 56,05°

STRONA 44 z 75

Kąt konstrukcyjny na wyjściu z palisady (β1w

′ = 32,2°; δ = 8,49°):

β1k
′
w

= β1w

′ | + δ | (4.65)

β1kw

′ = 32,2° + 8,49° = 40,69°

Kąt ustawienia profilu w palisadzie (β1kw

| = 56,05°; χ1w = 24,6°):
| γ = β1kw + χ1w
(4.66)

γ = 56,05° + 24,6° = 80,65°

Pod kątem γ przeprowadza się cięciwę profilu.

Badania wykazują, że korzystnymi w przypadku naddźwiękowego stopnia, są palisady
wentylatorów | zestawione | z profilów analogicznych do profilów skrzydłowych
przeznaczonych dla naddźwiękowych prędkości lotu. Profile te winny mieć małą grubość względną (g̅= 0,05 − 0,03), z maksymalną grubością profilu odsuniętą znacznie do tyłu (na około 50 – 60 % b), w celu otrzymania ostrej krawędzi natarcia. Zaokrąglone krawędzie natarcia i spływu wykonuje się promieniom równym r ≈ (0,005 − 0,007)b.

Zadowalające rezultaty mogą być osiągnięte przy wykorzystaniu profilów, w których linia
szkieletowa | składa | się | z | dwóch | łuków | o | różnych | promieniach: | [3]
(χ1w = 24,6°; χ1w

′ = 16,4°)

| | | | R1w =

a
sinχ1w
| | | | | | | | | (4.67)

R1w

′ =

bw − a
sinχ1
′ w

(4.68)

Gdzie: | a = 0,45 ∙ bw → a = 0,0945 m
Zatem: | R1w =
| 0,0945 sin24,6° = 0,227 m; R1w ′ = 0,21−0,0945 sin16,4°
= 0,409 m

Na rysunku 4.7 zostało przedstawiona graficzna interpretacja wygięcia linii szkieletowej.

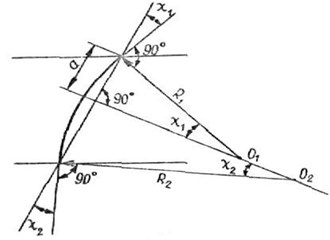
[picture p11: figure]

STRONA 45 z 75

Rys. 4.7. Wygięcie linii szkieletowej profilu według dwóch łuków o różnych promieniach [3].

Punkty 01 i 02 leżą na linii przecinającej cięciwę pod kątem prostym w miejscu maksymalnej strzałki ugięcia linii szkieletowej.

Maksymalna strzałka ugięcia linii szkieletowej wynosi:

fw = bw

1 − cos

Θw
2
2sin

Θw
2

(4.69)

fw = 0,21 ∙

1−cos

41°
2
2sin⁴¹°
2

= 0,018 m

Założono grubość względną profilu: g̅= 0,035

Maksymalna grubość profilu:

gw

= g̅∙ bw | (4.70)

gw = 0,035 ∙ 0,21 = 0,0074 m

Przy wyznaczonej maksymalnej grubości profilu, górna i dolna krzywizna profilu tworzone są łukami promieni opierającymi się na cięciwie i mającymi strzałki wygięcia odpowiednio wynoszące: fw −

gw
2

oraz fw +

gw
2

Promienie zaokrąglenia krawędzi natarcia i krawędzi spływu łopatki założono:

r1 ≈ r2 = 0,0025 ∙ bw | (4.71)

r1 = 0,52 mm

Maksymalną grubość profilu odsunięto do tyłu na 55% bw.

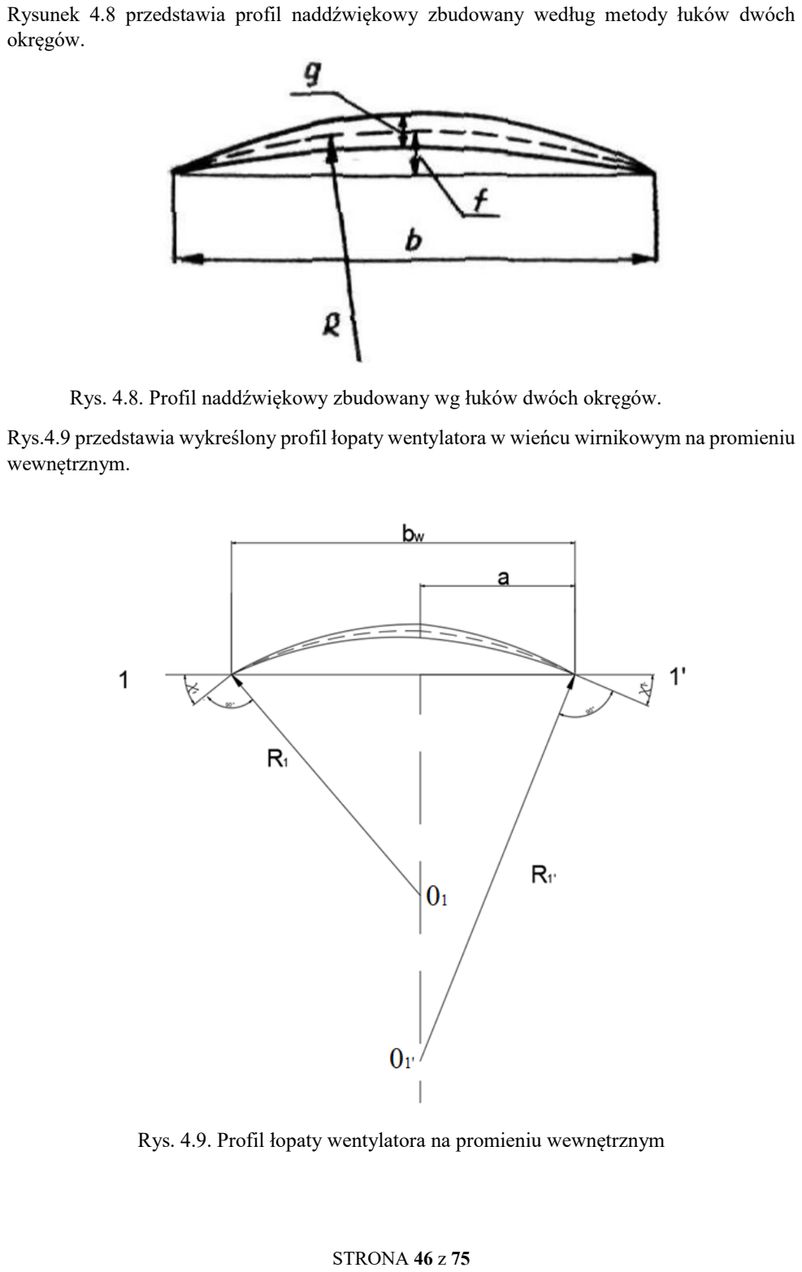
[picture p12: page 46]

STRONA 46 z 75

Rysunek 4.8 przedstawia profil naddźwiękowy zbudowany według metody łuków dwóch okręgów.

Rys. 4.8. Profil naddźwiękowy zbudowany wg łuków dwóch okręgów.

Rys.4.9 przedstawia wykreślony profil łopaty wentylatora w wieńcu wirnikowym na promieniu wewnętrznym.

Rys. 4.9. Profil łopaty wentylatora na promieniu wewnętrznym

STRONA 47 z 75

4.5. WYKREŚLENIE PROFILU ŁOPATY WIEŃCA WIRNIKOWEGO NA ŚREDNIM PROMIENIU.

Nominalny kąt skręcenia strumienia:
(Δβśr = 18,5°)

Δβśr

∗
= 1,18 ∙ Δβśr
(4.72)

Δβśr

∗ = 1,18 ∙ 18,5° = 21,83°

Cięciwa łopat wieńca wirnikowego wentylatora na średnim promieniu: bśr = 0,45 m

Założono kąt napływu palisad: i = −2°

Kąt wygięcia profilu:

Θśr =

Δβśr

∗ − i

1 − m ∙

tśr
bśr

(4.73)

Gdzie:

m = 0,18 + 0,23 ∙

2a

bśr

2
− 0,1 ∙

β1śr
′
50°

(4.74)

Dla β1śr

′ = 49,85° oraz

a

bśr

= 0,45 ⟶ m = 0,18 + 0,23 ∙ 0,9

2 − 0,1 ∙

49,85°
50°

= 0,2666

Podziałka palisady łopat wirnika wentylatora na średnim promieniu: (Dśr = 1,995 m; z = 22)

tśr =

πDśr
z

(4.75)

tśr =

3,1415∙1,995 m
22

= 0,284

Zatem kąt wygięcia profilu wynosi (Δβśr

∗ = 21,83°; i = −2°):

Θśr =

21,83° + 2°

1 − 0,2666 ∙

0,284
0,45

= 30,23°

Kąt odchylenia strumienia:

δ = m ∙ Θśr

∙

tśr

bśr

(4.76)

δ = 0,2666 ∙ 30,23° ∙

0,284
0,45

= 6,4°

STRONA 48 z 75

Przedni kąt wygięcia profilu:

χ1śr = Θśr

- 1,5 − 2 ∙

a

bśr

(4.77)

χ1śr = 30,23° ∙ (1,5 − 2 ∙ 0,45) = 18,14°

Tylny kąt wygięcia profilu:

χ1
′
śr

= Θśr − χ1śr
(4.78)

χ1śr

′ = 30,23° − 18,14° = 11,83°

Kąt konstrukcyjny na wejściu z palisady (β1śr = 31,35°;i = −2°):

β1kśr
= β1śr
+ i | (4.79)

β1kśr

= 29,35°

Kąt konstrukcyjny na wyjściu z palisady (β1śr

′ = 49,85°; δ = 6,4°):

β1k
′
śr

= β1śr

′ | + δ | (4.80)

β1kśr

′ = 49,85° + 6,4° = 56,25°

Kąt ustawienia profilu w palisadzie (β1kśr

| = 29,35°; χ1śr = 18,14°):
| γ = β1śr + χ1
(4.81)

γ = 29,35° + 18,14° = 47,49° Promienie łuków tworzących szkieletową profilu:

R1śr =

a
sinχ1śr

(4.82)

R1śr
′ =

bśr − a
sinχ1
′
śr

(4.83)

Gdzie: | a = 0,45 ∙ bśr → a = 0,45 ∙ 0,45 = 0,2025 m

STRONA 49 z 75

Zatem: | R1śr =

0,2025
sin18,14°

= 0,65 m; R1śr

′ =

0,45−0,2025
sin11,83°

= 1,207 m

Maksymalna strzałka ugięcia linii szkieletowej wynosi:

fśr = bśr

1 − cos

Θśr
2
2sin

Θśr
2

(4.84)

fśr = 0,45 ∙

1−cos

30,23°
2
2sin³⁰,23°
2

= 0,029 m

Założono grubość względną profilu: g̅= 0,035

Maksymalna grubość profilu:

gśr

= g̅∙ bśr | (4.85)

gśr = 0,035 ∙ 0,2 = 0,016 m

Przy wyznaczonej maksymalnej grubości profilu, górna i dolna krzywizna profilu tworzone są łukami promieni opierającymi się na cięciwie i mającymi strzałki wygięcia odpowiednio wynoszące: fśr −

gśr
2

oraz fśr +

gśr
2

Promienie zaokrąglenia krawędzi natarcia i krawędzi spływu łopatki założono:

r1 ≈ r2 = 0,0025 ∙ bśr
(4.86)

r1 = 1,125 mm

Maksymalną grubość profilu odsunięto do tyłu na 55% bśr

Rys.4.9 przedstawia wykreślony profil łopaty wentylatora w wieńcu wirnikowym na średnim promieniu.

Rys. 4.9. Profil łopaty wentylatora na średnim promieniu.

STRONA 50 z 75

### 4.6. WYKREŚLENIE PROFILU ŁOPATY WIEŃCA WIRNIKOWEGO NA PROMIENIU

AAAZEWNĘTRZNYM

Nominalny kąt skręcenia strumienia:
(Δβz = 6,65°)

Δβz

∗
= 1,18 ∙ Δβz
(4.87)

Δβz

∗ = 1,18° ∙ 6,65° = 7,85°

Cięciwa łopat wieńca wirnikowego wentylatora na średnim promieniu: bz = 0,3 m

Założono kąt napływu palisad: i = −2°

Kąt wygięcia profilu:

Θz =

Δβz

∗ − i

1 − m ∙

tz
bz

(4.88)

Gdzie:

m = 0,18 + 0,23 ∙

2a
bz

2
− 0,1 ∙

β1z
′
50°

(4.89)

Dla β1z

′ = 30,75° oraz

a
bz

= 0,45 ⟶ m = 0,18 + 0,23 ∙ (0,9)

2 − 0,1 ∙

30,75°
50°

= 0,3048

Podziałka palisady łopat wirnika wentylatora na średnim promieniu: (Dz = 2,493 m; z = 22)

tz =

πDz
z

(4.90)

tz =

3,1415∙2,493
22

= 0,887

Zatem kąt wygięcia profilu wynosi (Δβz

∗ = 7,85°; i = −2°):

Θz =

7,85° + 2°

1 − 0,3048 ∙

0,887
0,3

= 20,69°

Kąt odchylenia strumienia:

δ = m ∙ Θz

∙

tz
bz

(4.91)

δ = 0,3048 ∙ 20,69° ∙

0,887
0,3

= 10,84°

STRONA 51 z 75

Przedni kąt wygięcia profilu:

χ1z = Θz

- 1,5 − 2 ∙

a
bz

(4.92)

χ1z = 20,69° ∙ (1,5 − 2 ∙ 0,45) = 12,41°

Tylny kąt wygięcia profilu:

χ1
′
z

= Θz − χ1z
(4.93)

χ1z

′ = 20,69° − 12,41° = 8,28°

Kąt konstrukcyjny na wejściu z palisady (β1z = 24,1°; i = −2°):

β1kz
= β1z
+ i | (4.94)

β1kz

= 26,1°

Kąt konstrukcyjny na wyjściu z palisady (β1z

′ = 30,75°; δ = 10,84°):

β1k
′
z

= β1z
′ + δ | (4.95)

β1kz

′ = 30,75° + 10,84° = 41,59°

Kąt ustawienia profilu w palisadzie (β1kz

| = 26,1°; χ1z = 12,41°):
| γ = β1kz + χ1
(4.96)

γ = 26,1° + 12,41° = 38,51°

Promienie łuków tworzących szkieletową:

R1z =

a
sinχ1z

(4.97)

R1z

′ =

bz − a
sinχ1
′
z

(4.98)

Gdzie: | a = 0,45 ∙ bz → a = 0,135 m

STRONA 52 z 75

Zatem: | R1z =

0,135
sin12,41°

= 0,628 m; R1z

′ =

0,3−0,135
sin8,28°

= 1,145 m

Maksymalna strzałka ugięcia linii szkieletowej wynosi:

fz = bz

1 − cos

Θz
2
2sin

Θz
2

(4.99)

fz = 0,3

1−cos

20,69°
2
2sin²⁰,69°
2

= 0,0135 m

Założono grubość względną profilu: g̅= 0,035

Maksymalna grubość profilu:

gz

= g̅∙ bz
(4.100)

gz = 0,0105 m

Przy wyznaczonej maksymalnej grubości profilu, górna i dolna krzywizna profilu tworzone są łukami promieni opierającymi się na cięciwie i mającymi strzałki wygięcia odpowiednio wynoszące: fz −

gz
2

oraz fz +

gz
2

Promienie zaokrąglenia krawędzi natarcia i krawędzi spływu łopatki założono:

r1 ≈ r2 = 0,0025 ∙ bz | (4.101)

r1 = 0,75 mm

Maksymalną grubość profilu odsunięto do tyłu na 45% bz

Rysunek 4.10 przedstawia wykreślony profil łopaty wentylatora w wieńcu wirnikowym na promieniu zewnętrznym.

Rys. 4.10. Schematyczny rysunek profilu łopaty wentylatora.

STRONA 53 z 75

### 4.7. WYKREŚLENIE PROFILI ŁOPATY WIEŃCA DYFUZOROWEGO WENTYLATORA

Obliczenia pozwalające wykreślić profil wieńca dyfuzorowego (aparatu kierującego), przeprowadza się w analogiczny sposób jak dla wieńca.

W celu uniknięcia drgań rezonansowych, liczny łopat wieńca wirnika i wieńca dyfuzorowego nie powinny być wielokrotnościami.

- Liczba łopat aparatu kierującego: zAK = 21
- Kąt napływu palisad i = 0°
- Grubość względna profilu g̅= 0,04

Z racji analogii przeprowadzanych obliczeń, sporządzono tabelę (4.1) zawierającą wyniki obliczeń dla wieńca dyfuzorowego na promieniu wewnętrznym, średnim oraz zewnętrznym, niezbędne do wykreślenia profili.

Tab. 4.1. Dane wynikowe dla poszczególnych promieni.

Na podstawie danych z tabeli 4.1 wykreślono profile łopaty wieńca dyfuzorowego dla trzech promieni (rys.4.11, rys.4.12 oraz rys.4.13).

L.p. | Wielkość
1 | b | 0.16 | 0.2 | 0.22
2 | m | 0.1863 | 0.1863 | 0.1863
3 | | 0.104 | 0.274 | 0.373
4 | | 18.63° | 30.09° | 43.72°
5 | | 21.98° | 35.5° | 51.59°
6 | | 25.86° | 45.39° | 68.11°
7 | | 3.88° | 9.89° | 16.52°
8 | | 15.52° | 27.23° | 40.86°
9 | | 10.34° | 18.16° | 27.25°
10 | | 32.2° | 49.88° | 30.75°
11 | | 36.08° | 59.77° | 47.27°
12 | | 47.72° | 77.11° | 71.61°
13 | | 0.269 m | 0.196 m | 0.151 m
14 | | 0.49 m | 0.353 m | 0.264 m
15 | f | 9 mm | 20 mm | 33 mm
16 | g | 6.4 mm | 8 mm | 8.8 mm
17 | | 1.6 mm | 2 mm | 2.2 mm

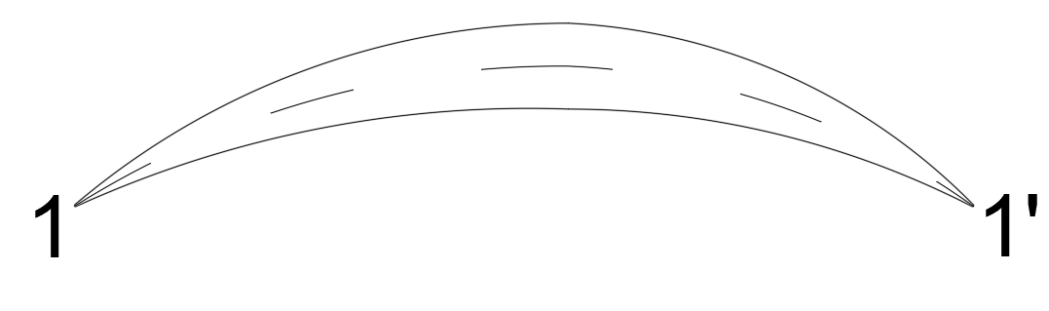
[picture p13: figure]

STRONA 54 z 75

Rys. 4.11. Schematyczny rysunek profilu łopaty AK wentylatora na promieniu wewnętrznym.

Rys. 4.12. Schematyczny rysunek profilu łopaty AK wentylatora na średnim promieniu.

Rys. 4.13. Schematyczny rysunek profilu łopaty AK wentylatora na promieniu zewnętrznym.

Odległość między wieńcami w stopniu dobiera się w granicach (0,15 − 0,25)b, co daje najmniejsze wymiary osiowe sprężarki przy dopuszczalnej nierównomierności strumienia na wejściu do następnego elementu.

STRONA 55 z 75

5.OBLICZENIA WYTRZYMAŁOŚCIOWE ŁOPAT WIRNIKOWYCH, ZAMKÓW I TARCZY WENTYLATORA NA ROZCIĄGANIE SIŁĄ MASOWĄ.

Obliczenia wytrzymałościowe są niezbędne do sprawdzenia, czy dany materiał będzie odpowiedni dla projektowanej konstrukcji, i czy dana maszyna bądź urządzenie wytrzyma generowane naprężenia wynikające z sił, które są powszechnym czynnikiem podczas eksploatacji. W tym rozdziale skupiono się na obliczeniach wytrzymałościowych łopat wirnikowych, zamków i tarczy wentylatora na rozciąganie siłą masową.

5.1. | OBLICZENIA | WYTRZYMAŁOŚCIOWE | ŁOPAT | WIRNIKA | WENTYLATORA | NA
ROZCIĄGANIE SIŁĄ MASOWĄ.

Obciążenia decydujące o wartości maksymalnych naprężeń w łopatkach wirnikowych stanowią siły odśrodkowe bezwładności, działające na ich masę. Siły odśrodkowe bezwładności wywołują w łopatkach naprężenia rozciągające, których wartości są zmienne wzdłuż pióra. Na rysunku 4.1 przedstawiono łopatkę wirnikową oraz charakterystyczne dla łopat wentylatorowych przebiegi zmian wartości przekrojów poprzecznych łopatek, w zależności od długości piór. [4]

Rys. 5.1. Rozkłady przekrojów poprzecznych łopatek wirnikowych. [4]

Elementarną siłę określa zależność:

dF = dm ∙ r ∙ ω

2
- A(r) ∙ r ∙ dr | (5.1)

W celu wyznaczenia naprężeń rozciągających w dowolnym przekroju A(R) na promieniu R wirnika, należy wyznaczyć sumaryczną siłę odśrodkową F(R) działającą na część pióra łopatki, znajdującą się powyżej promienia R i podzielić jej wartość przez przekrój A(R) łopatki na tym promieniu:

σ(R) =

1
A(R)

dF =

R1

R

ρ ∙ ω

2
∙

1
A(R)

A(r) ∙ r ∙ dr

R1

R

(5.2)

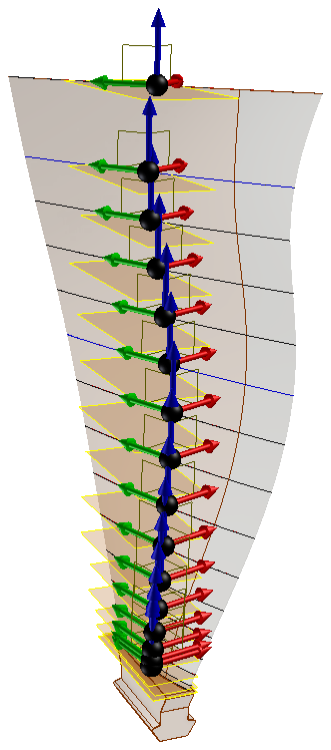
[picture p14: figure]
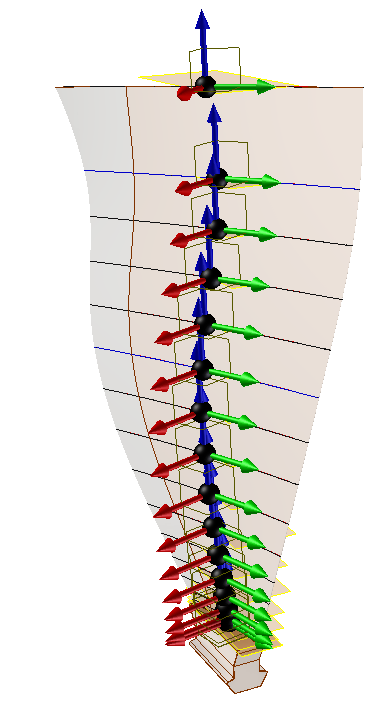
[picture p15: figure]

STRONA 56 z 75

Ze względu na wzajemne wpływy czynników konstrukcyjnych, przepływowych, wytrzymałościowych, dynamicznych i wreszcie technicznych na wynikowy przebieg zmian powierzchni przekrojów poprzecznych piór łopatek wirnikowych, przebiegów tych nie można opisać zależnością analityczną; są one przedstawione w postaci odpowiedniej tabeli. W takim przypadku, z dostateczną dokładnością, dla celów projektowych, wykorzystuje się w obliczeniach wytrzymałościowych piór łopatek wirnikowych metody przybliżone.

Na podstawie tabelarycznego zestawienia przekrojów (Tab. 5.1) sporządzono wykres rozkładu przekrojów poprzecznych wzdłuż pióra (rys.5.3). Przekroje łopaty wieńca wirnikowego (rys.5.2) zagęszczono w pobliżu podstawy pióra ze względu na większą intensywność zmian w tym obszarze. [4]

Rys. 5.2. Przekroje wzdłuż rozpiętości łopaty wieńca wirnikowego

STRONA 57 z 75

Tab. 5.1. Zestawienie średnich wartości przekrojów, odległości między poszczególnymi przekrojami oraz odległości poszczególnych płaszczyzn od powierzchni podstawy pióra.

Rys. 5.3. Rozkład pól powierzchni przekrojów poprzecznych łopaty wieńca wirnikowego wentylatora.

Dla poszczególnych odcinków (od 0-1 do 14-15) pióra łopaty uśredniono powierzchnię przekroju poprzecznego. Następnie wyznaczono objętość tego odcinka oraz jego masę.

L.p | Aśr_i | ΔLi | Rśr i
| mm^2 | mm | mm
0 - 1 | 1264 | 10 | 5
1 - 2 | 1302 | 20 | 20
2 - 3 | 1363 | 30 | 45
3 - 4 | 1440 | 40 | 80
4 - 5 | 1501 | 50 | 125
5 - 6 | 1566 | 60 | 180
6 - 7 | 1612 | 70 | 249
7 - 8 | 1633 | 70 | 315
8 - 9 | 1640 | 70 | 390
9 - 10 | 1567 | 70 | 460
10 - 11 | 1488 | 70 | 530
11 - 12 | 1466 | 70 | 595
12 - 13 | 1467 | 70 | 665
13 - 14 | 1471 | 70 | 740
14 - 15 | 1492 | 70 | 840

STRONA 58 z 75

Obliczenia naprężeń przeprowadza się, zaczynając od przekroju najbliższego wierzchołkowi łopaty (w tym przypadku jest to przekrój 15). Dla każdego odcinka pióra łopaty uśrednia się powierzchnię, wyznacza się objętość tego odcinka, a następnie jego masę.

Siłę działającą na odcinek pióra opisuje następujący wzór:

F(0−1) = ρ ∙ ω

2
- Aśr (0−1)
- ΔL(0−1)
- Rśr(0−1)
(5.3)

gdzie: Rśr(0−1) − promień środka masy rozważanego odcinka pióra łopaty

Aśr(0−1) − średnia wartość powierzchni przekroju poprzecznego odcinka pióra łopaty ograniczonego płaszczyznami 0 i 1

Naprężenie w przekroju 1 łopatki można wyznaczyć z zależności:

σ(F1

) =

F(0−1)
A1

= ρ ∙ ω

2
∙

Aśr (0−1)
A1
- ΔL(0−1)
- Rśr(0−1)

(5.4)

W celu wyznaczenia naprężeń o największej wartości należy obliczyć siły odśrodkowe bezwładności działające na wszystkie odcinki i podzielić je przez pole powierzchni przekroju podstawy pióra (AP = A0 = 1252 mm²
).Ogólna zależność na naprężenia w dowolnym przekroju i ma postać:

σ(Ai

) =

1
Ai

Fi

i=n

i=1

= ρ ∙ ω

2
∙

1
Ai
- Aśr i
- ΔL(i)
- Rśr(i)

i=n

i=1

(5.5)

Zatem dla przekroju przy podstawie pióra łopaty (przekrój ostatni licząc od wierzchołka

pióra – przekrój 0) zależność przyjmuje następującą postać:

σ Ap =

1
Ap

Fi

i=15

i=1

= ρ ∙ ω

2
∙

1
Ap
- Aśr i
- ΔL(i)
- Rśr(i)

i=15

i=1

(5.6)

Założono, że cała łopata jest wykonana z jednorodnego materiału, jakim jest tytan. Gęstość tytanu wynosi ρTi = 4,506 g
cm³

Prędkość kątową wieńca wirnikowego wentylatora można wyliczyć z następującej zależności:

ω =

π ∙ n
30

(5.7)

Jeśli prędkość obrotowa wieńca wirnikowego wyznaczona w rozdziale 3 (wzór (3.13)) wynosi n = 2912 obr
min

, to prędkość kątowa osiąga wartość:

ω =

3,1415 ∙ 2912
30 = 305

1
s

STRONA 59 z 75

Naprężenia w przekroju podstawy wynoszą:

σobl = σ Ap = ρ ∙ ω

2
∙

1
Ap
- Aśr i
- ΔL(i)
- Rśr(i)

i=15

i=1

=

= ρ ∙ ω

2
∙

1
Ap
- Aśr14−15 ∙ ΔL14−15 ∙ Rśr14−15 | + Aśr13−14 ∙ ΔL13−14 ∙ Rśr13−14
+ Aśr12−13 ∙ ΔL12−13 ∙ Rśr12−13 | + Aśr11−12 ∙ ΔL11−12 ∙ Rśr11−12
+ Aśr10−11 ∙ ΔL10−11 ∙ Rśr10−11 | + Aśr9−10 ∙ ΔL9−10 ∙ Rśr9−10

+ Aśr8−9

- ΔL8−9
- Rśr8−9

+ Aśr 7−8

- ΔL7−8
- Rśr7−8

+ Aśr6−7
- ΔL6−7
- Rśr6−7

+ Aśr5−6

- ΔL5−6
- Rśr5−6

+ Aśr 4−5

- ΔL4−5
- Rśr4−5

+ Aśr3−4
- ΔL3−4
- Rśr3−4

+ Aśr2−3
- ΔL2−3
- Rśr2−3

+ Aśr1−2

- ΔL1−2
- Rśr1−2

+ Aśr0−1

- ΔL0−1
- Rśr0−1

σobl = σ Ap =

1
1252
- 4,506 ∙ 305

2
- 10

−3

- [(1492 ∙ 70 ∙ 840) + (1471 ∙ 70 ∙ 740) + (1467 ∙ 70 ∙ 665) + (1466 ∙ 70 ∙ 595) + (1488 ∙ 70 ∙ 530) + (1567 ∙ 70 ∙ 460) + (1640 ∙ 70 ∙ 390) + (1633 ∙ 70 ∙ 315) + (1612 ∙ 70 ∙ 249) + (1566 ∙ 60 ∙ 180) + (1501 ∙ 50 ∙ 125) + (1440 ∙ 40 ∙ 80) + (1363 ∙ 30 ∙ 45) + (1302 ∙ 20 ∙ 20) + (1264 ∙ 10 ∙ 5)] = 181,153 MPa

σobl = 181,153 MPa

Współczynnik bezpieczeństwa definiuje następujący wzór ν =

σdop

σobl

σdop − naprężenia dopuszczalne
σmax − naprężenia maksymalne

Dla tytanu granica proporcjonalności (granica stosowalności prawa Hooke’a) wynosi: RHTi = 800 MPa

zakłada się, że:

σdop ≈ RH

zatem wzór określający współczynnik bezpieczeństwa przyjmuje następującą postać:

ν =

RH

σobl

(5.8)

ν =

800
181,153

= 4,41

Konstrukcje lotnicze charakteryzują się ν = 1,5. Łopaty wentylatora są narażone na zderzenia z ciałami obcymi (ptactwo) podczas pracy, dlatego też współczynnik bezpieczeństwa osiągnął tak sporą wartość.

Zakłada się naprężenia dopuszczalne na rozciąganie jednostronnie tętniące:

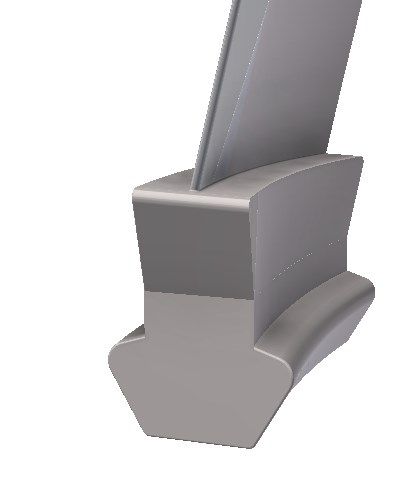
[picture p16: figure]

STRONA 60 z 75

σdop rj

= 0,35 ∙ RH | (5.9)

σdoprj

= 0,35 ∙ 800 = 280 MPa

Dla σobl = 181,153 MPa warunek wytrzymałościowy σobl ≤ σdop został spełniony.

### 5.2. OBLICZENIA WYTRZYMAŁOŚCIOWE ZAMKÓW WENTYLATORA NA ROZCIĄGANIE SIŁĄ

ZZI MASOWĄ.

Łopatki wirnikowe wentylatora są połączone z tarczami nośnymi za pomocą tzw. zamków, stanowiących jednolitą całość z piórami łopatek. Wszystkie obciążenia działające na łopatki, są przenoszone na tarcze nośne wirników za pośrednictwem zamków. W ramach pracy zaprojektowano zamek trapezowy (rys.5.4).

Rys. 5.4. Zamek trapezowy łopaty wieńca wirnikowego wentylatora.

Zamki łopat oblicza się, wyznaczając wartości nacisków powierzchniowych i naprężeń rozciągających. Do obliczeń wytrzymałościowych zamka łopaty wieńca wirnikowego wentylatora niezbędne są charakterystyczne wymiary, przedstawione na rysunku 5.5.

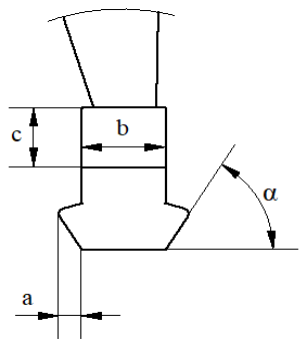
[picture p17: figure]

STRONA 61 z 75

Rys. 5.5. Charakterystyczne wymiary zamka łopaty wentylatora.

a = 17 mm; b = 43 mm; c = 40 mm; α = 58°

Obliczenia zamków trapezowych przeprowadza się analogicznie jak dla zamków prostokątnych, uwzględniając jedynie nachylenie płaszczyzn styku zamka łopatki z tarczą; przy nachyleniu występuje zwiększenie nacisków, w porównaniu z zamkiem prostokątnym, z uwagi na tzw. działanie klina. [4]

Naciski powierzchniowe wyznacza poniższa zależność:

p =

FΣ
2 ∙ a ∙ l

(5.10)

gdzie:

FΣ − całkowita siła odśrodkowa bezwładności działająca na masę pióra łopaty wraz z zamkiem
l − długość zamka (l = 223 mm (wartość wyznaczona w programie SolidWorks))

Całkowita siła odśrodkowa bezwładności działająca na masę pióra wraz z zamkiem składa się z sumy siły odśrodkowej bezwładności działającej na pióro (Fp) oraz siły odśrodkowej bezwładności działającej na zamek (Fz).

FΣ = Fp + Fz
(5.11)

Siłę odśrodkową bezwładności działającą na masę pióra można wyliczyć z następującego wzoru:

Fp =

mp v

2
r

= mω

2
r = mpω

2
rp

(5.12)

mp − masa pióra łopaty (mz = 7,069 kg)
rp − odległość środka masy pióra od osi obrotu wieńca wirnikowego (rp = 0,834 m) ω − prędkość kątowa wieńca wirnikowego (ω = 305 ¹
s

)

Fp = 7,069 ∙ 305²
- 0,834 = 548,433 kN

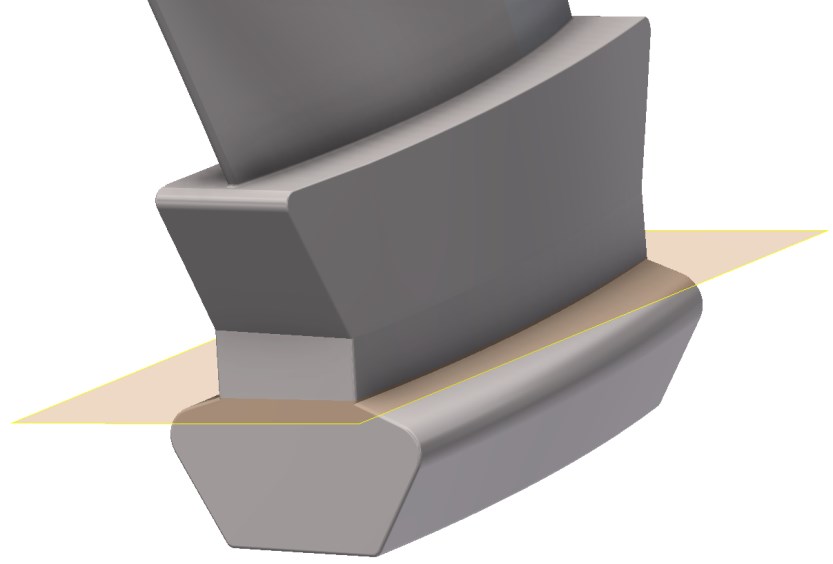
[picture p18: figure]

STRONA 62 z 75

Zakładając, że zamek (jak również pióro) są wykonane z jednorodnego materiału (tytanu) siłę działająca na zamek łopaty można wyrazić następującym wzorem:

Fz =

mzv

2
r

= mzω

2
rz

(5.13)

mz − masa zamka łopaty (mz = 4,566 kg)
r − odległość środka masy zamka od osi obrotu wieńca wirnikowego (r = 0,294 m) ω − prędkość kątowa wieńca wirnikowego (ω = 305 ¹
s

)

mz oraz r wyznaczono w programie SolidWorks.

zatem: | Fz = 4,566 ∙ 305²
- 0,294 = 124,877 kN

Całkowita siła odśrodkowa bezwładności wynosi:

| FΣ = 548,433 kN + 124,877 kN = 673,31 kN
| p =
| 673,31 2 ∙ 0,017 ∙ 0,223 = 88,8 MPa

Naprężenia rozciągające w „szyjce” zamka wynoszą:

| σr =

FΣ

′
b ∙ l

(5.14)

FΣ

′ − siła odśrodkowa działająca na masę pióra łopatki (oraz części zamka), znajdującej się powyżej przekroju obliczeniowego
l − długość zamka (l = 223 mm)
b − grubość szyjki zamka (b = 43 mm)

W tym przypadku rozpatruje się część łopaty powyżej przekroju obliczeniowego przedstawionego na rys 5.6.

Rys. 5.6. | Zamek łopaty
wieńca wirnikowego z płaszczyzną wyznaczającą przekrój obliczeniowy.

STRONA 63 z 75

FΣ

′ wyznacza się analogicznie jak FΣ (nie bierze się pod uwagę części zamka poniżej przekroju obliczeniowego).

FΣ

′ =

młv

2
rł

= młω

2rł
(5.15)

mł − masa rozpatrywanej części łopaty (mł = 9,468 kg)
rł − odległość środka masy rozpatrywanej części zamka i pióra łopaty od osi obrotu wieńca wirnikowego (rł = 0,355 m)
ω − prędkość kątowa wieńca wirnikowego (ω = 305 ¹
s

)

mł oraz rł wyznaczono w programie SolidWorks.

FΣ

′ = 9,468 ∙ 305
2
- 0,355 = 312,67 kN

σr =

312 670
0,043 ∙ 0,223 = 32,6 MPa

### 5.3. OBLICZENIA WYTRZYMAŁOŚCIOWE TARCZY WENTYLATORA NA ROZCIĄGANIE

ZZZISIŁĄ MASOWĄ.

Jako podstawę do analizy wpływu oddzielnych obciążeń na naprężenia w tarczy, przyjęto model tarczy o stałej grubości, jako względnie łatwy do ocen jakościowych i ilościowych przy użyciu prostych wzorów obliczeniowych. Naprężenia wywołane obciążeniami są jednakowe na całej grubości tarczy na każdym promieniu (tzw. płaski stan naprężeń).[12]

Zależności na naprężenia w tarczy o stałej grubości bez otworu centralnego określają równania:

σr1 =

3 + ν
8

ρ ∙ U

2
1 −

r
R

2

σu1 =

3 + ν
8

ρ ∙ U

2
1 −

1 + 3ν
3 + ν

r
R

2

(5.16)

gdzie:

U = ω ∙ R oznacza prędkość obwodową na zewnętrznym promieniu tarczy. ν − współczynnik Poissona (dla tytanu ν = 0,34)
σr1 − naprężenia promieniowe
σu1 − naprężenia obwodowe
ρ − gęstość (dla tytanu ρ = 4 506 kg
m³

)
R − promień zewnętrzny tarczy
r − promień bieżący

Na podstawie zależności opisanych we wzorze 5.16, sporządzono obliczenia dla różnych promieni (od środka tarczy do promienia zewnętrznego co 10 mm), które pozwoliły wyznaczyć rozkład naprężeń promieniowych i obwodowych w tarczy (rys.5.7).

STRONA 64 z 75

Rys. 5.7. Rozkład naprężeń promieniowych i obwodowych od obciążeń masowych tarczy o stałej grubości bez otworu centralnego.

Naprężenia promieniowe i obwodowe osiągają największe wartości w centralnej części tarczy i wraz z oddalaniem się od środka tarczy wartość naprężeń maleje.

Do analizy wpływu obciążeń wieńcowych na rozkład naprężeń w tarczy o stałej grubości przyjęto, że tarcza wirnikowa jest poddana wyłącznie działaniu tych naprężeń.[4]

Naprężenia wywołane obciążeniem wieńcowym w tarczy o stałej grubości, są niezależne od promienia i wynoszą:

σr2 = σu2 = σw =

(Fp + Fz + Fg) ∙ z
2 ∙ π ∙ R ∙ b

(5.17)

Fp − siła odśrodkowa działająca na pióro łopaty (Fp = 548,433 kN) Fz − siła odśrodkowa działająca na zamek łopaty (Fz = 124,877 kN) Fg − siła odśrodkowa działająca na garb w tarczy (Fg = 103,76 kN) b – grubość tarczy (b = 205 mm)
z – liczba łopat (z = 22)
R − promień zewnętrzny tarczy

Fg wyznacza się analogicznie jak FΣ (bierze się pod uwagę tylko elementy tarczy pomiędzy łopatami – tzw. garby).

Fg =

mgv

2
rg

= mgω

2rg
(5.18)

mg − masa garbu mg = 3,38 kg

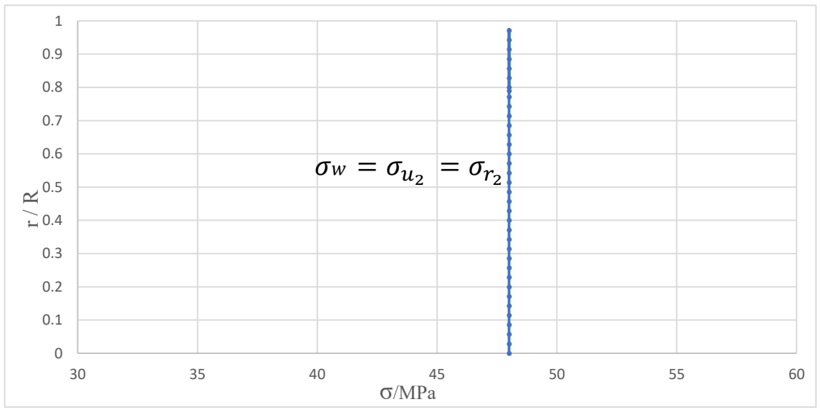
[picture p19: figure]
σ/MPa

STRONA 65 z 75

rg − odległość środka masy garbu od osi obrotu wieńca wirnikowego rg = 0,33 m ω − prędkość kątowa wieńca wirnikowego (ω = 305 ¹
s

)

mg oraz rg wyznaczono w programie SolidWorks.

Fg = 3,38 ∙ 305

2
- 0,33 = 103,76 kN

Zatem wartość naprężeń wieńcowych w tarczy wynosi:

σw =

(548 433 + 124 877 + 103 760) ∙ 22
2 ∙ 3,1415 ∙ 0,276 ∙ 0,205 | = 48 MPa

Na podstawie zależności 5.17 sporządzono wykres przedstawiający rozkład naprężeń wieńcowych w tarczy wieńca wirnikowego wentylatora (rys.5.8).

Rys. 5.8. Rozkład naprężeń promieniowych i obwodowych od obciążenia wieńcowego w tarczy wirnika wentylatora.

Znając wartości obciążeń związanych z masą tarczy oraz obciążeń wieńcowych, wyznaczono naprężenia wypadkowe (sumaryczne).

Wypadkowe naprężenia obwodowe oraz promieniowe określają równania:

σrΣ = σr1 + σr2
σuΣ = σu1 + σu2

(5.19)

Wykorzystując zależność 5.19 sporządzono wykres naprężeń sumarycznych.

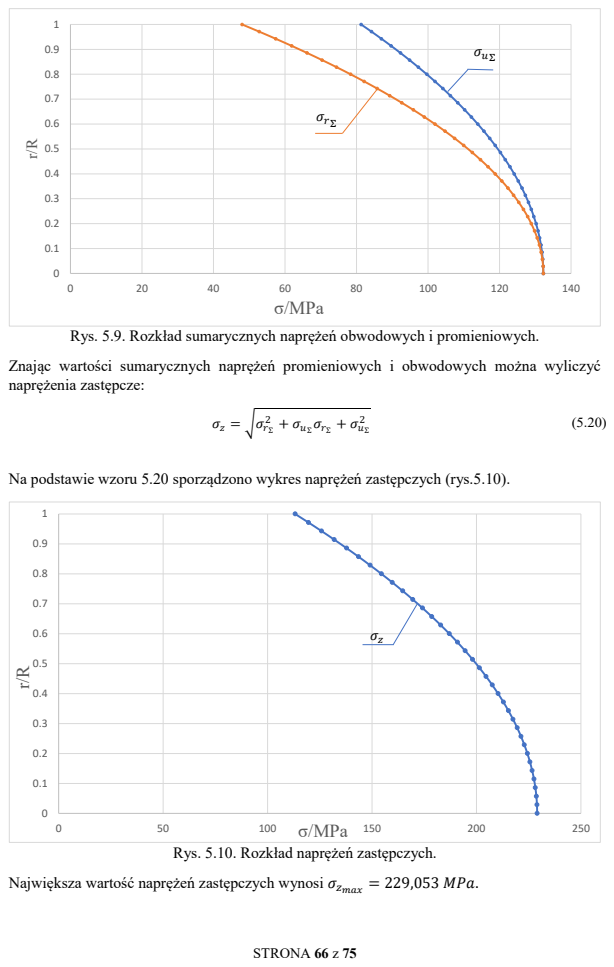
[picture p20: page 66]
STRONA 66 z 75; σz = σrΣ; 2 + σuΣ; σrΣ + σuΣ; σ/MPa; σrΣ; σuΣ

Rys. 5.9. Rozkład sumarycznych naprężeń obwodowych i promieniowych.

Znając wartości sumarycznych naprężeń promieniowych i obwodowych można wyliczyć
naprężenia zastępcze:

Na podstawie wzoru 5.20 sporządzono wykres naprężeń zastępczych (rys.5.10).

Rys. 5.10. Rozkład naprężeń zastępczych.

Największa wartość naprężeń zastępczych wynosi σzmax = 229,053 MPa.

STRONA 67 z 75

Dla tytanu granica proporcjonalności (granica stosowalności prawa Hooke’a) wynosi: RHTi = 800 MPa

zakłada się, że:

σdop ≈ RH

zatem wzór określający współczynnik bezpieczeństwa przyjmuje następującą postać:

ν =

RH

σzmax

(5.21)

ν =

800
229,053 = 3,492

Zakłada się naprężenia dopuszczalne na rozciąganie jednostronnie tętniące:

σdop rj

= 0,35 ∙ RH | (5.22)

σdoprj

= 0,35 ∙ 800 = 280 MPa

Dla σzmax = 229,053 MPa warunek wytrzymałościowy σobl ≤ σdop został spełniony.

W przypadku tarcz wirnikowych nagrzanych równomiernie (o stałej temperaturze wzdłuż promienia) można tak ukształtować grubość tarczy b wzdłuż promienia r, aby osiągnąć stałą wartość naprężeń σr = σu = σ = const. Istotną zaletą tak ukształtowanej tarczy będzie wysoki stopień wykorzystania materiału konstrukcyjnego (w każdym jej punkcie wytężenie materiału będzie jednakowe), co pozwala uzyskać najmniejszą masę konstrukcji przy zadanej minimalnej wartości współczynnika bezpieczeństwa. Jest to ważny aspekt w przypadku zastosowania drogich materiałów konstrukcyjnych (np.: tytan). Taka tarcza jest mniej sztywna zarówno wzdłuż promienia, jak i na zginanie na jej obwodzie, a także trudniejsza pod względem technologii wykonania. [4]

Wartość współczynnika bezpieczeństwa można wyrazić następującym wzorem:

ν(r) =

σdop

(r)
σz(r)

(5.23)

gdzie:
σdop ≈ RH = 800 MPa − naprężenia dopuszczalne

Na podstawie wzoru 5.23 otrzymano różne wartości współczynnika bezpieczeństwa tarczy w zależności od jej promienia, które przedstawiono w formie wykresu na rysunku 5.11.

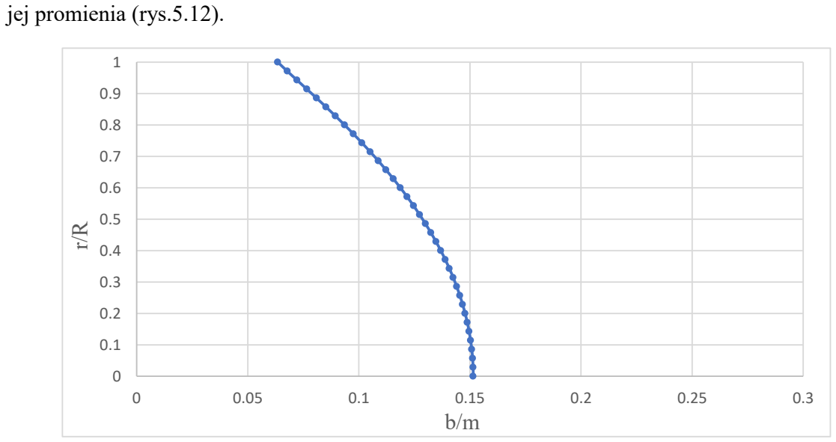
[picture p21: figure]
jej promienia (rys.5.12).

STRONA 68 z 75

Rys. 5.11. Rozkład współczynnika bezpieczeństwa, założonej wartości współczynnika bezpieczeństwa oraz naprężeń zastępczych wzdłuż promienia tarczy.

Znając rozkład współczynnika bezpieczeństwa przyjęto jego stałą wartość νzał = 2,5. Zatem, na każdym promieniu można wyznaczyć grubość b tarczy, przy której byłby spełniony warunek założonego współczynnika bezpieczeństwa wg następującej zależności: [4]

b(r) = b0

νzał
ν(r)

(5.24)

gdzie: b0 − grubość tarczy (przed profilowaniem); b0 = 0,205 m

Na podstawie zależności 5.24 sporządzono wykres obrazujący zmianę grubości tarczy wzdłuż

Rys. 5.12. Grubość tarczy w zależności od jej promienia.

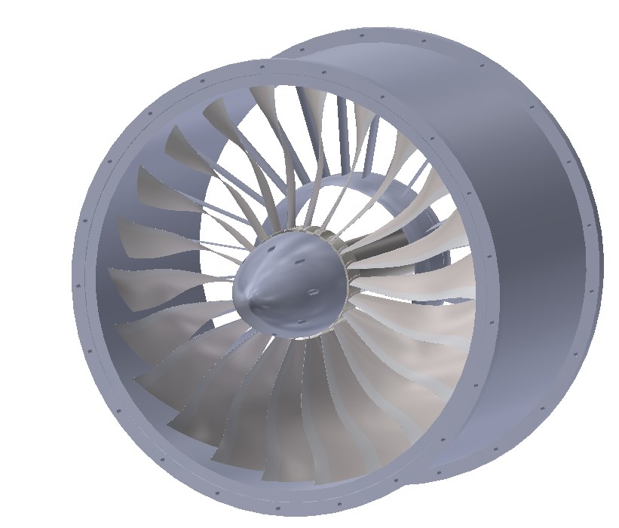
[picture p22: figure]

STRONA 69 z 75

W programie SolidWorks zaprojektowano uproszczoną tarczę (bez miejsc na zamki łopat) przed profilowaniem oraz po profilowaniu. Przedstawiony jeden etap profilowania tarczy wieńca wirnikowego wentylatora zredukował masę z 353,788 kg do 246,928 kg.

Dalsze etapy profilowania tarczy charakteryzują się dużą złożonością, dlatego w celu dalszego profilowania powinno się przeprowadzić obliczenia metodą elementów skończonych (wykorzystując m.in. takie programy jak ANSYS).

### 6. MODEL WENTYLATORA I RYSUNKI WYKONAWCZE TARCZY ORAZ

ZZŁOPATY.
Tarczę wieńca wirnikowego, łopaty, aparat kierujący wraz z obudową oraz kołpak wentylatora zaprojektowano w programie SolidWorks. Kołpak wentylatora składa się z dwóch części. Część granicząca z tarczą stanowi jednocześnie element blokujący ruch łopaty w kierunku osiowym. Wszystkie połączenia, które można zauważyć na rys 6.2, rys.6.3 oraz rys.6.4 są śrubowe. Drugim elementem blokującym ruch łopat w kierunku osiowym jest wał, połączony z tarczą.

Rys. 6.1. Rzut aksonometryczny wentylatora (widok z przodu).

STRONA 70 z 75

Rys. 6.2. Rzut aksonometryczny wentylatora (widok od tyłu).

Rys. 6.3. Mocowanie kołpaka do tarczy.

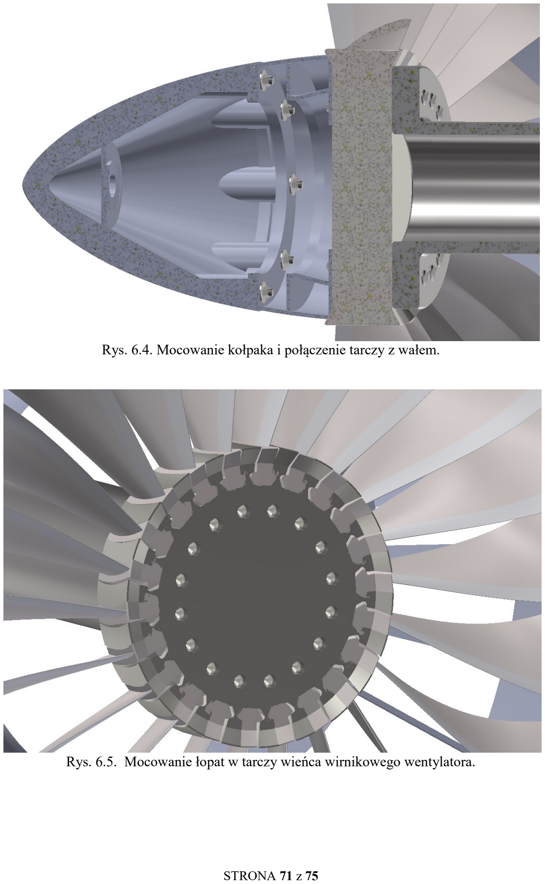
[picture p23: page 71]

STRONA 71 z 75

Rys. 6.4. Mocowanie kołpaka i połączenie tarczy z wałem.

Rys. 6.5. Mocowanie łopat w tarczy wieńca wirnikowego wentylatora.

STRONA 72 z 75

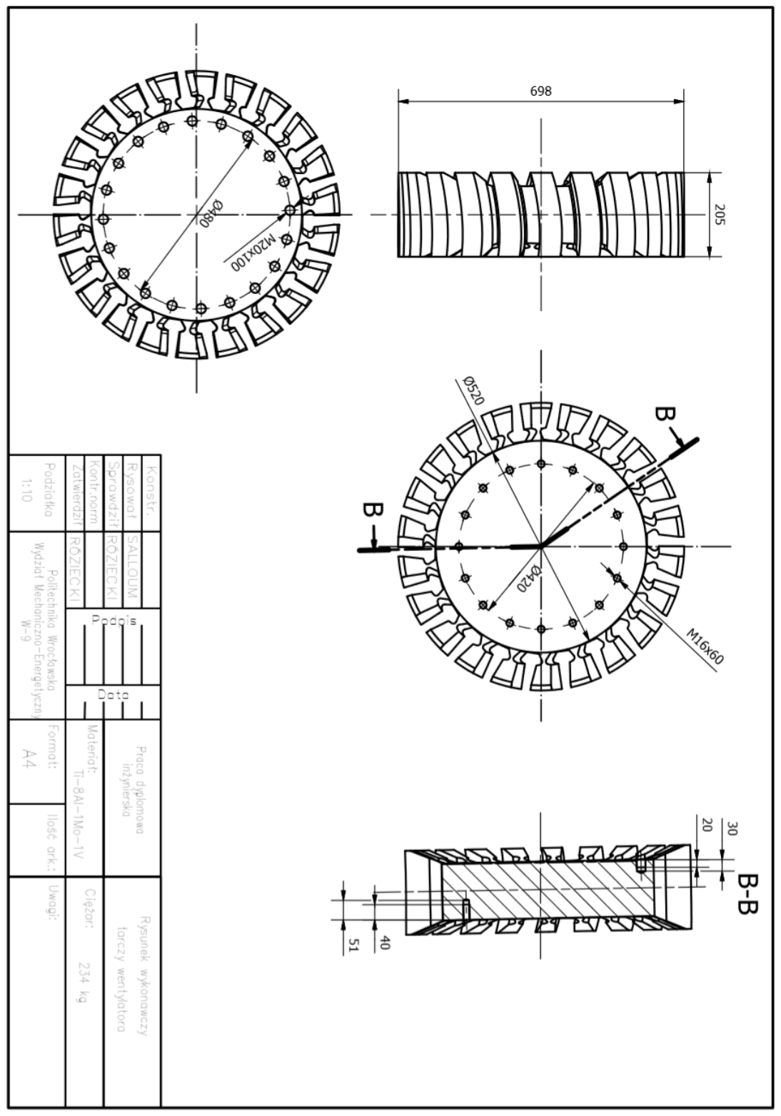
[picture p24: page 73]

STRONA 73 z 75

STRONA 74 z 75

### 7. PODSUMOWANIE I WNIOSKI

W | silnikach | dwuprzepływowych | turbinowo | odrzutowych | o | wysokim | stopniu
dwuprzepływowości wentylator pełni istotną rolę. Projektowanie tego podzespołu wymaga znajomości zjawisk fizycznych zachodzących podczas pracy silnika. Opisując matematycznie zjawiska fizyczne, ukształtowano elementy wentylatora (profilowanie pióra łopaty). Pogodzenie ze sobą ograniczeń, np.: wynikających z wytrzymałości materiału oraz aspektu finansowego (koszt materiału) wraz z technologią wykonania danego obiektu jest zadaniem wyjątkowo trudnym i złożonym, wymagającym znajomości wielu dziedzin nauki, co jest wyzwaniem dla inżynierów.

Następnym etapem pracy, realizowanej już jako praca magisterska, mogłyby być badania tunelowe wydrukowanej (w drukarce 3D) łopaty. Korzystając z programów ANSYS oraz Nastran Patran, wykorzysując metody numeryczne (np.: MES czy CFD) można by było przeprowadzić symulacje dające dokładniejsze wyniki naprężeń w łopacie i tarczy oraz ukształtować lepsze pod względem aerodynamicznym łopaty (wykorzystujące zjawisko kryzysu falowego spowodowanego osiąganiem prędkości naddźwiękowych końcówek łopat wieńca wirnikowego wentylatora w sposób bardziej efektywny).

STRONA 75 z 75

### 8. SPIS POZYCJI LITERATUROWYCH

[1] Balicki W.,Chachurski R.,Głowacki P.,Godzimirski J. i inni - Lotnicze Silniki cccTurbinowe – część I,
[2] Balicki W.,Chachurski R.,Głowacki P.,Godzimirski J. i inni - Lotnicze Silniki cccTurbinowe – część II,
[3] Dzierżanowski P.,Otyś J.,Szczeciński S.,Wiatrek R.: Konstrukcja silników lotniczych IIIII– projektowanie przejściowe i dyplomowe;
[4] Dżygadło Z.,Łyżwiński M.,Otyś J.: Napędy lotnicze – zespoły wirnikowe silników ccIcturbinowych, WKIŁ 1982;
[5] Https://www.wikiwand.com/en/General_Electric_CF6 ; z dnia 25.10.2019.
[6] Https://www.mtu.de/engines/commercial-aircraft-engines/widebody-jets/genx/; ZZIz dnia 25.10.2019 r,
[7] Https://www.rolls-royce.com/products-and-services/civil-aerospace/airlines/rb211-p IIIII524gh-and-t.aspx#/; z dnia 25.10.2019 r,
[8] Https://www.gknaerospace.com/globalassets/downloads/aerospace---fan-blade-repair-ZZ capabilities/rb211-535-fan-blade.pdf/; z dnia 25.10.2019 r,
[9] Https://grabcad.com/library/general-electric-ge90-94b-turbofan-engine-1,
Iz dnia 25.10.2019 r,
[10] Https://www.geaviation.com/commercial/engines/ge90-engine; z dnia 25.10.2019 r,
[11] Https://www.mtu.e/engines/commercial-aircraft-engines/widebody-jets/genx/;
z dnia 25.10.2019 r,
[12] Https://www.geaviation.com/commercial/engines/genx-engine, z dnia 25.10.2019 r.

STRONA 76 z 75

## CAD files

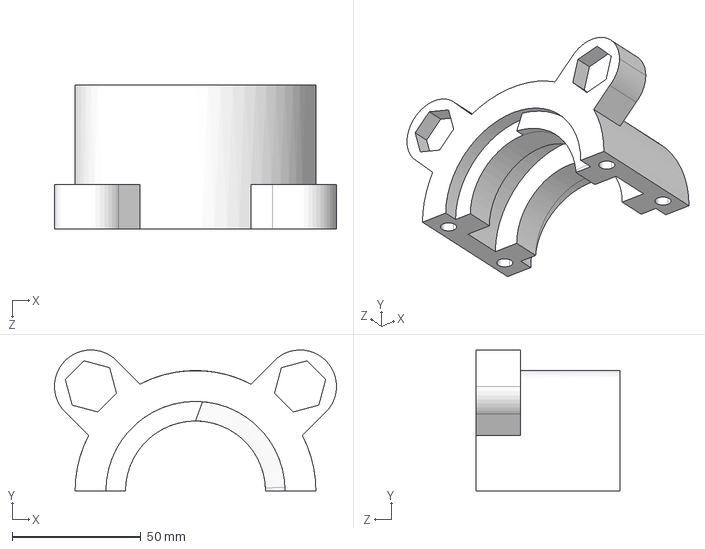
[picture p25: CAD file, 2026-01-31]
Harvester Prototype/Gauder_magnet_case_right.STEP
109.3 x 54.7 x 56.0 mm

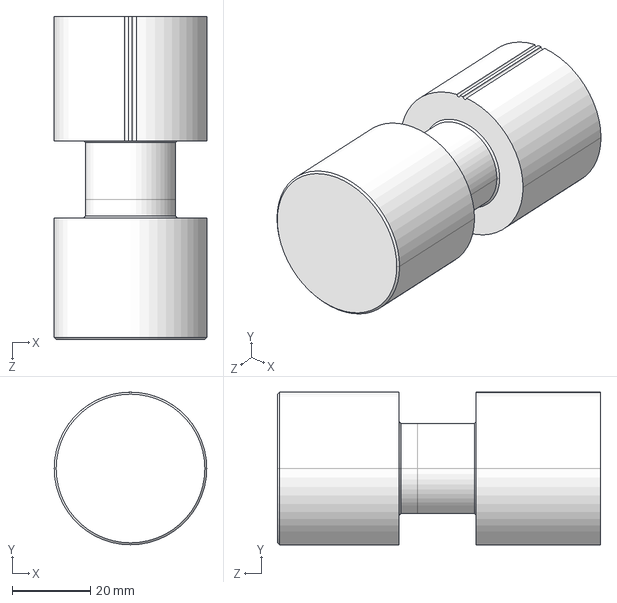
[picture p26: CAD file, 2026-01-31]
Harvester Prototype/Gauder_coil_case_OD35.STEP
39.0 x 39.0 x 82.6 mm

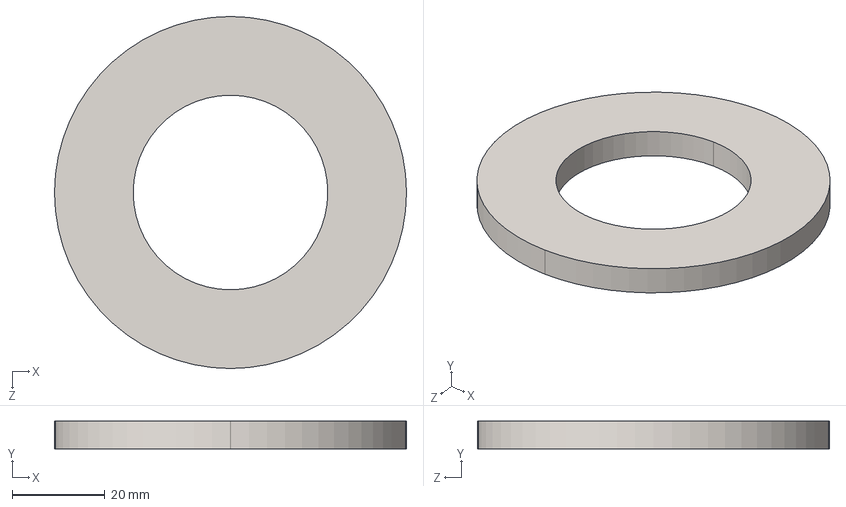
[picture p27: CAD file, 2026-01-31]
Harvester Prototype/Gauder_magnes.STEP
76.0 x 6.00 x 76.0 mm

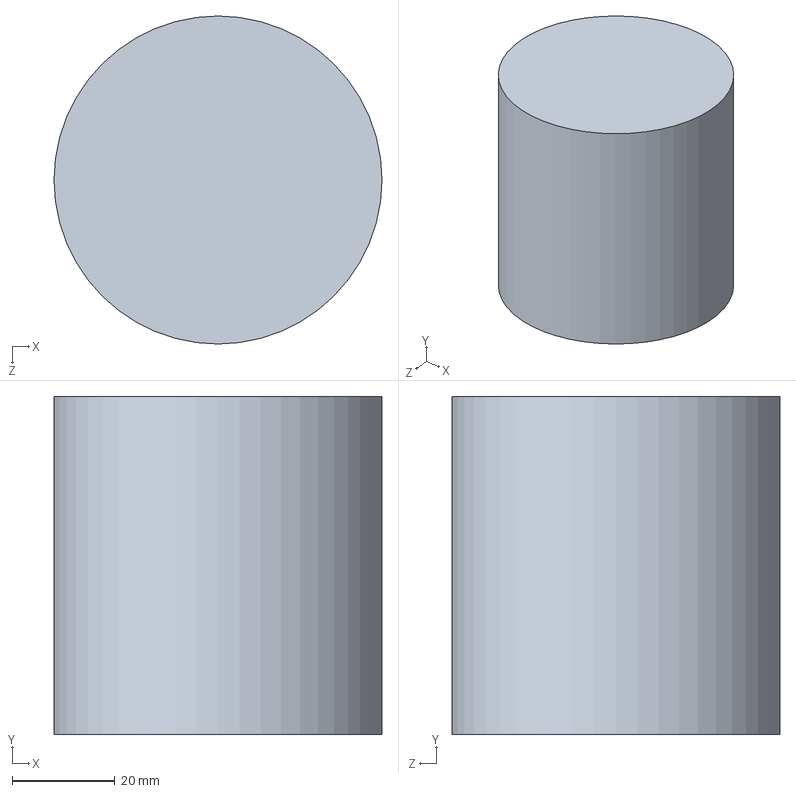
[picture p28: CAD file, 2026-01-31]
Harvester Prototype/weightForSimulation.SLDPRT
64.0 x 66.0 x 64.0 mm

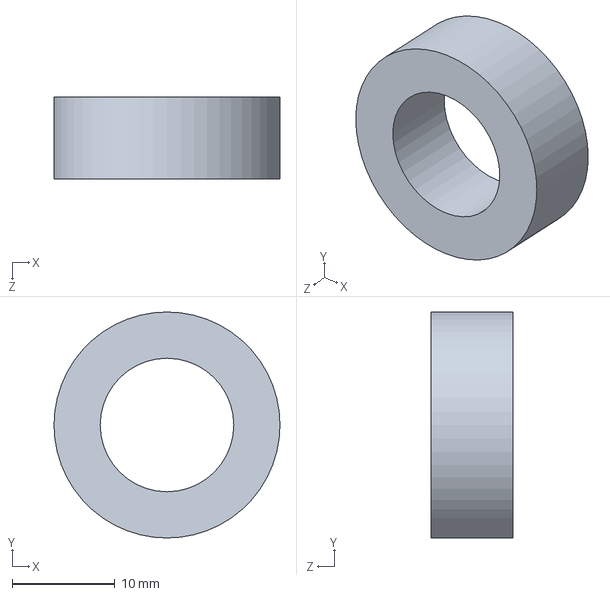
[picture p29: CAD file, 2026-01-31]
Harvester Prototype/Gaude_coil.SLDPRT
22.0 x 22.0 x 8.00 mm

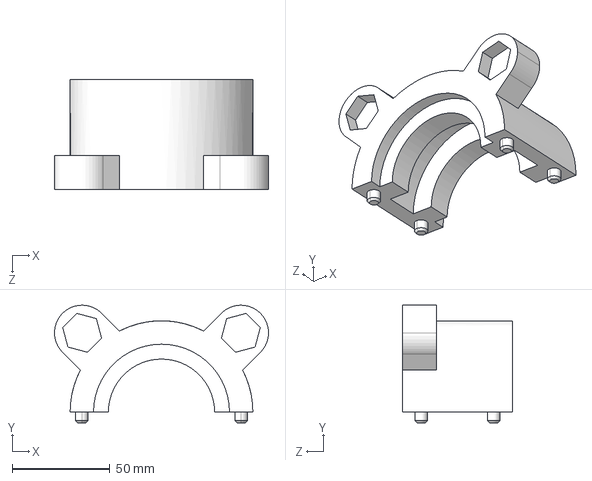
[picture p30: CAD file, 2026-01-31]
Harvester Prototype/Gauder_magnet_case_left.STEP
109.3 x 60.1 x 56.0 mm

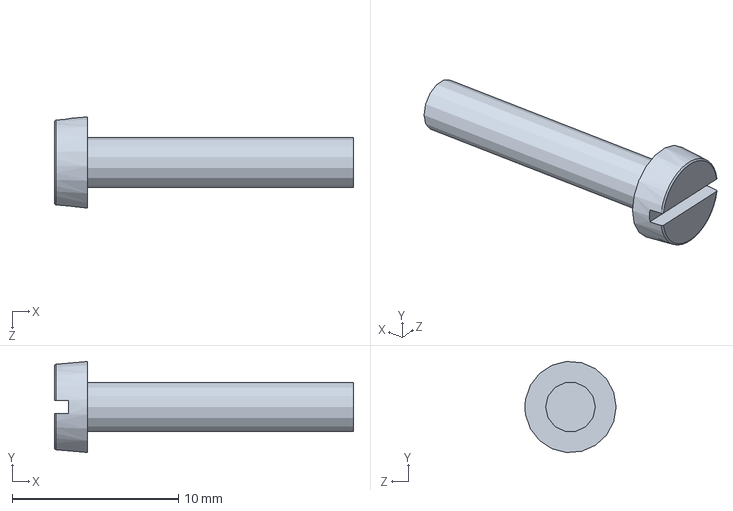
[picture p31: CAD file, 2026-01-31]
Harvester Prototype/M316.SLDPRT
18.0 x 5.48 x 5.50 mm

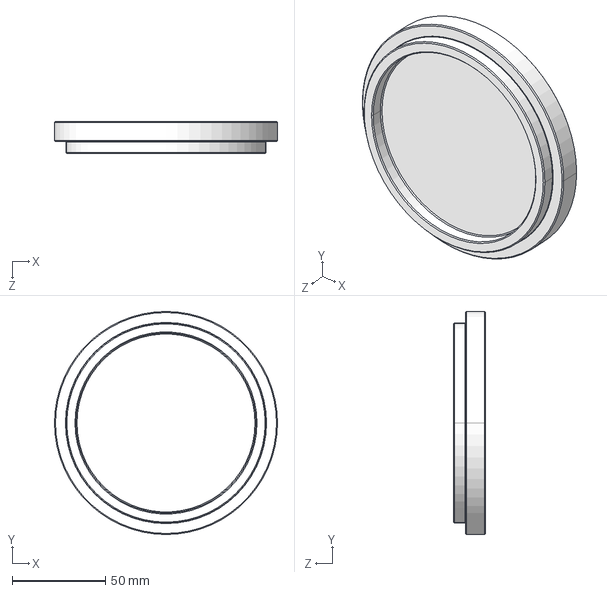
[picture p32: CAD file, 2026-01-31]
Harvester Prototype/Gauder_base_cap.STEP
119.4 x 119.4 x 17.4 mm

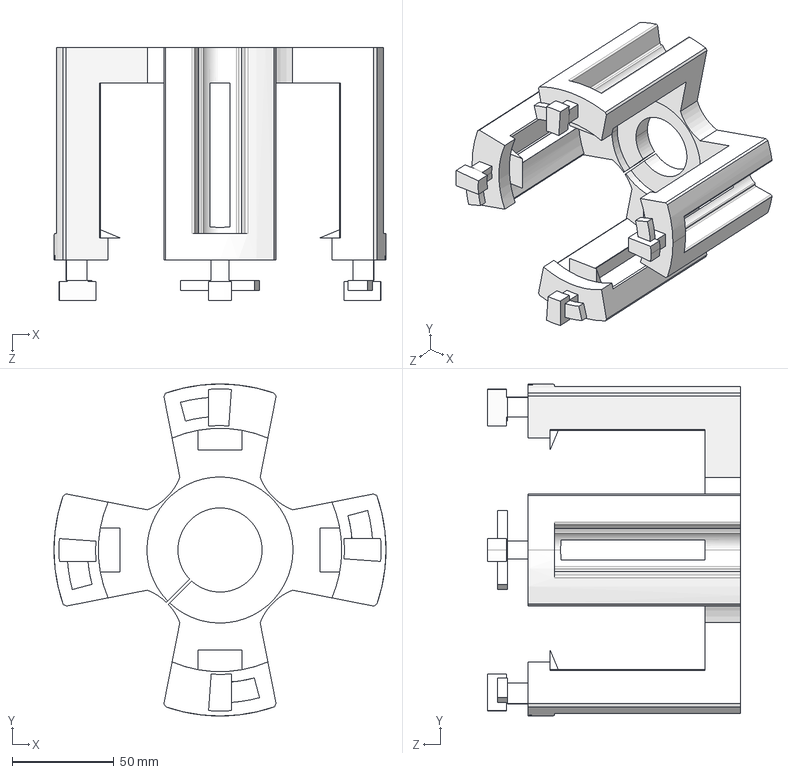
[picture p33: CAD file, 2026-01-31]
Harvester Prototype/gauder_outer_case.STEP
162.9 x 162.9 x 124.0 mm

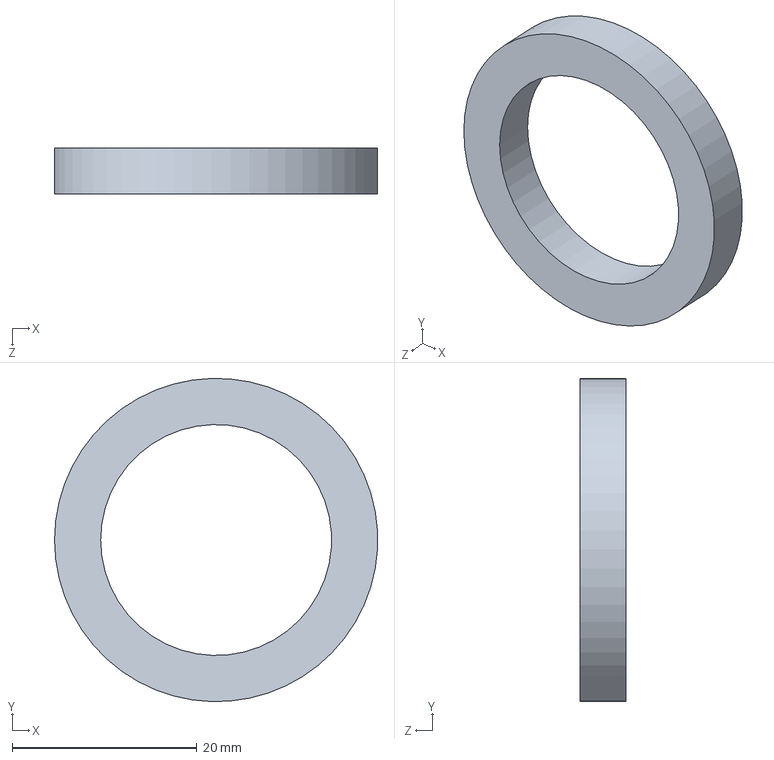
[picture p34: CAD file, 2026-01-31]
Harvester Prototype/Gouder_magnet_OD76.SLDPRT
35.0 x 35.0 x 5.00 mm

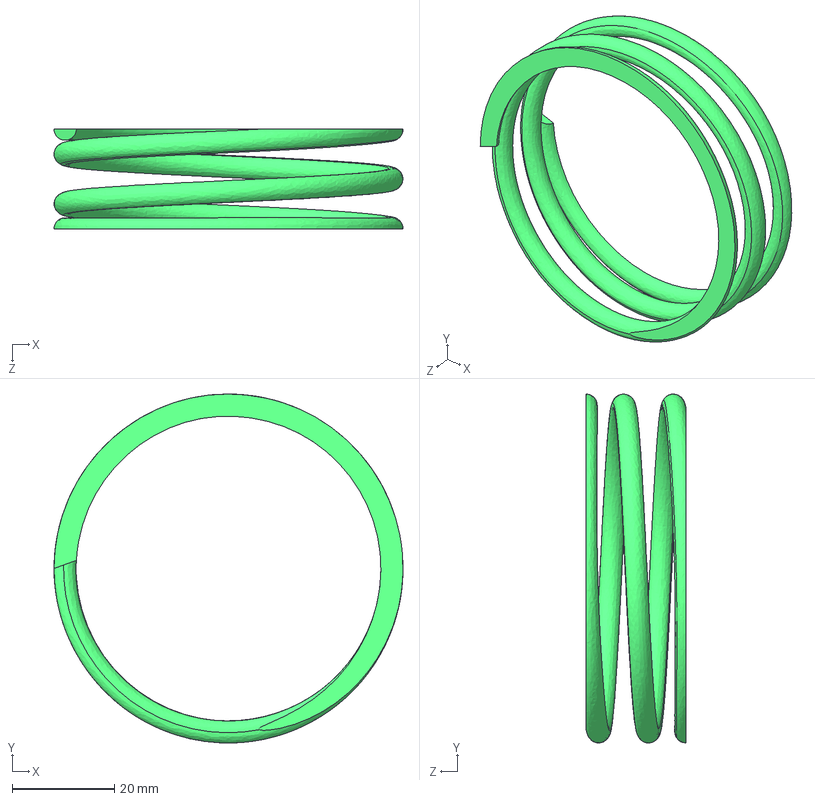
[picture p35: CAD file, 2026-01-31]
Harvester Prototype/springs_OD35.STEP
68.4 x 68.4 x 19.5 mm

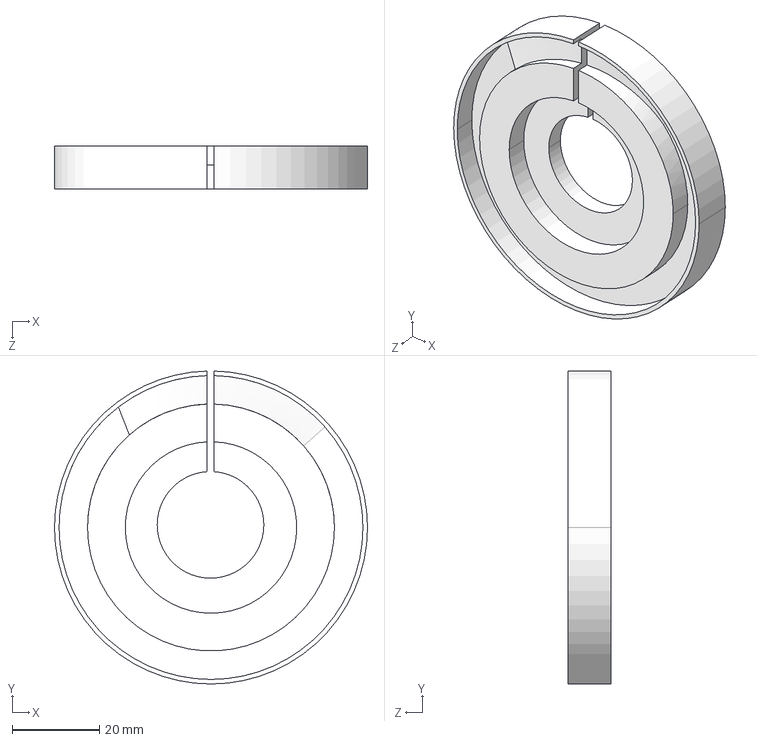
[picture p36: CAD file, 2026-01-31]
Harvester Prototype/Gauder_coil_cap.STEP
71.6 x 71.6 x 9.77 mm

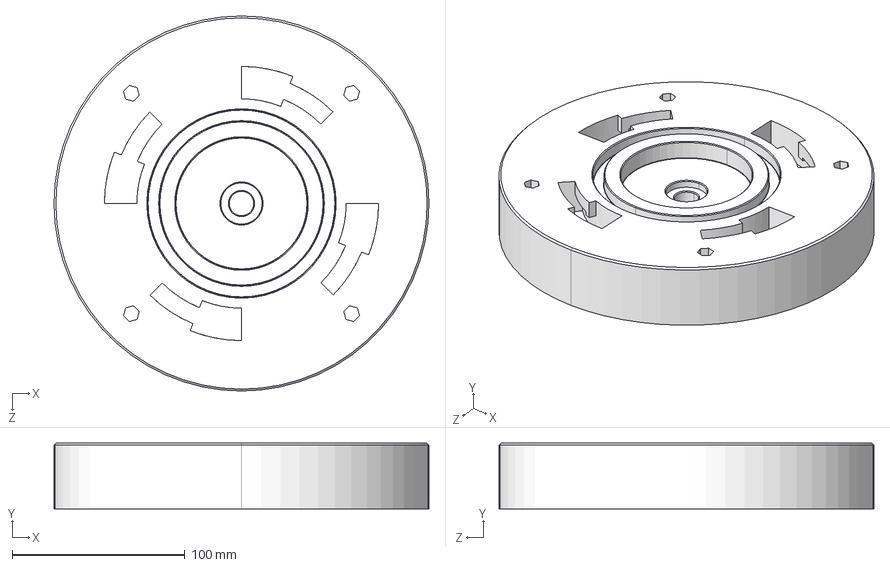
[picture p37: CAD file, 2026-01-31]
Harvester Prototype/Gauder_base.STEP
217.1 x 38.0 x 217.1 mm

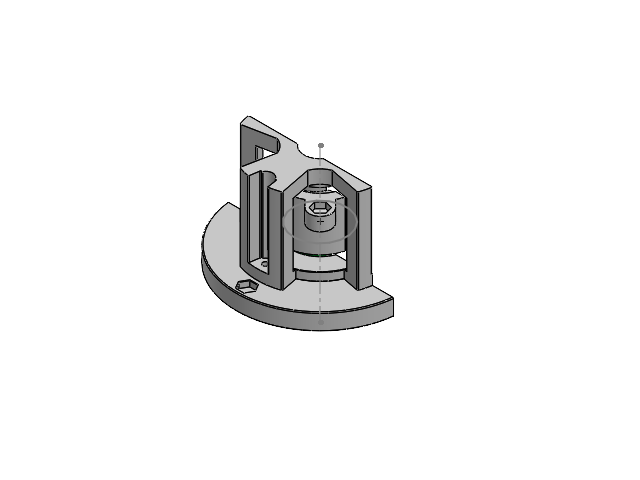
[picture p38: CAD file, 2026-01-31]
Harvester Prototype/Gauder_Assembly.SLDASM
p1p_Carc_inf
p1p_O1_Base
p1p_N_carc_sup
coil_case_OD35
p1p_N_tapa_carc_sup
coil_1c_OD35
p1p_magnetcase_dr
p1p_magnetcase_esq
springs_OD35

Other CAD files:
Harvester Prototype/Gauder_magnet_case_assembly.SLDASM
Harvester Prototype/Gauder_assempby_separate.SLDASM
Harvester Prototype/Assem1step214.STEP
Harvester Prototype/Assem1.STEP
Harvester Prototype/Assem1.SLDASM
Harvester Prototype/Gauder_base.SLDPRT
Harvester Prototype/Gauder_base_cap.SLDPRT
Harvester Prototype/Gauder_coil_cap.SLDPRT
Harvester Prototype/Gauder_coil_case_OD35.SLDPRT
Harvester Prototype/Gauder_magnes.SLDPRT
Harvester Prototype/Gauder_magnet_case_left.SLDPRT
Harvester Prototype/Gauder_magnet_case_right.SLDPRT
Harvester Prototype/gauder_outer_case.SLDPRT
Harvester Prototype/springs_OD35.SLDPRT
